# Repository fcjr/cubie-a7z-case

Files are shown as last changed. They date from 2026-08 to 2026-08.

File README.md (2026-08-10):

# Cubie A7Z case

A two-piece snap-fit case for the
[Radxa Cubie A7Z](https://radxa.com/products/cubie/a7z/). The board drops
into a tray, a lid clicks on top. No screws, no supports, no glue.

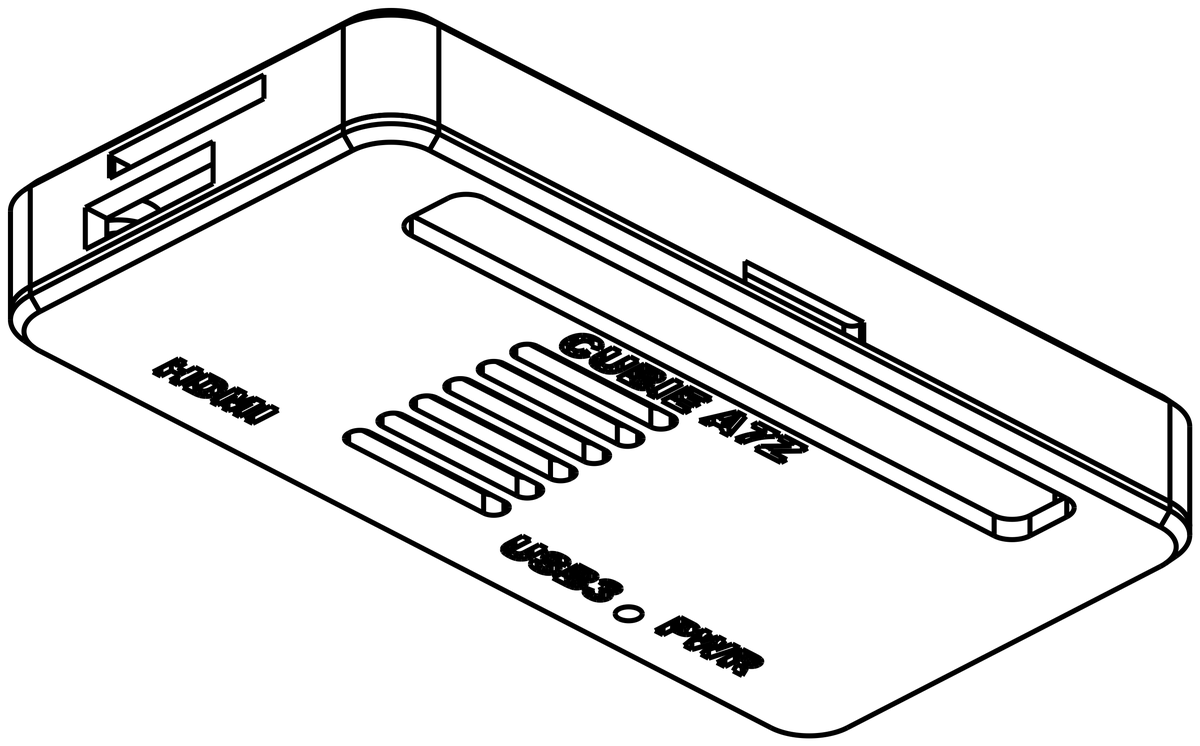
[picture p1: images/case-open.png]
The assembled case


## Print two parts

Everything ready to print is in [`output/`](output/). Take one tray and one
lid — any pairing works.

### Tray

|  |  |
|---|---|
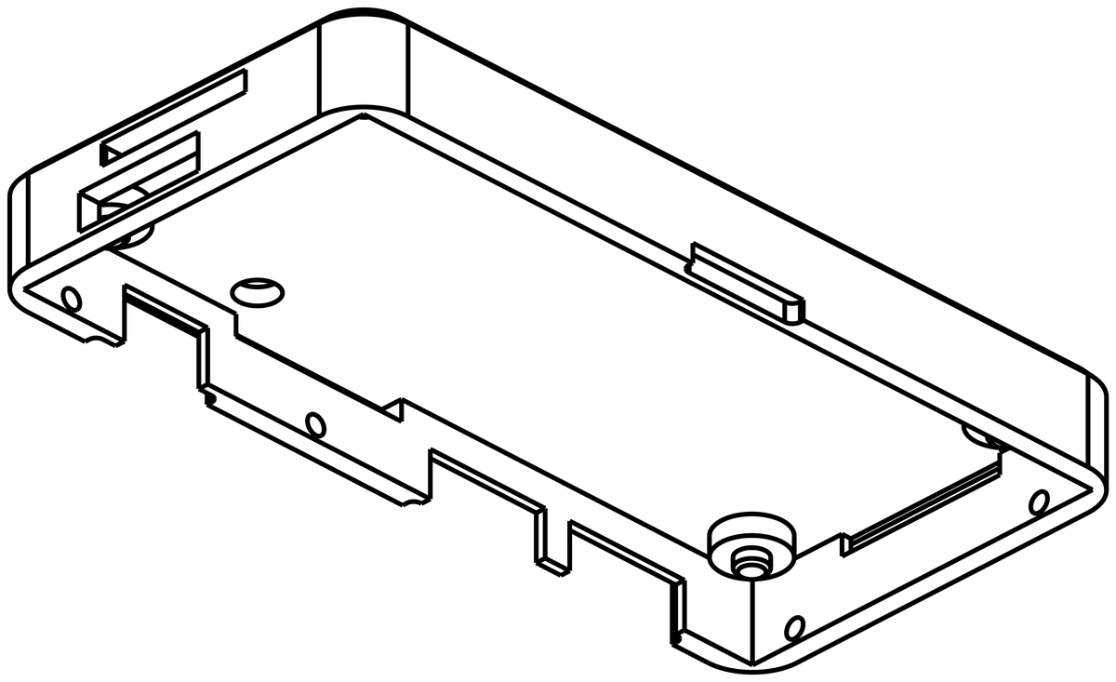
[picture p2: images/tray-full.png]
Tray with cable exits
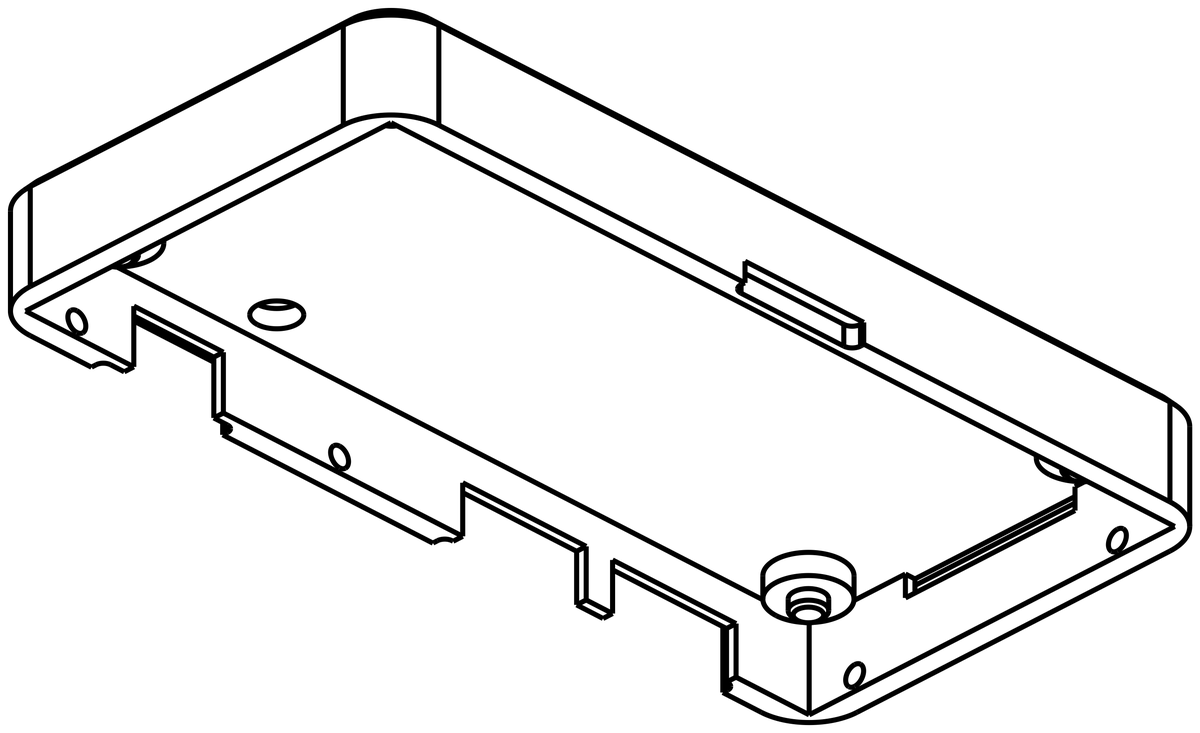
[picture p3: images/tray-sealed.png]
Sealed tray
|  |  |
| **`bottom.stl`** — openings for the PCIe ribbon, a CSI camera, the WiFi antenna and a fan. | **`bottom-sealed.stl`** — none of those openings, for a cleaner box. |

Every tray keeps the ports, the microSD slot and the boot button reachable.

### Lid

|  |  |  |
|---|---|---|
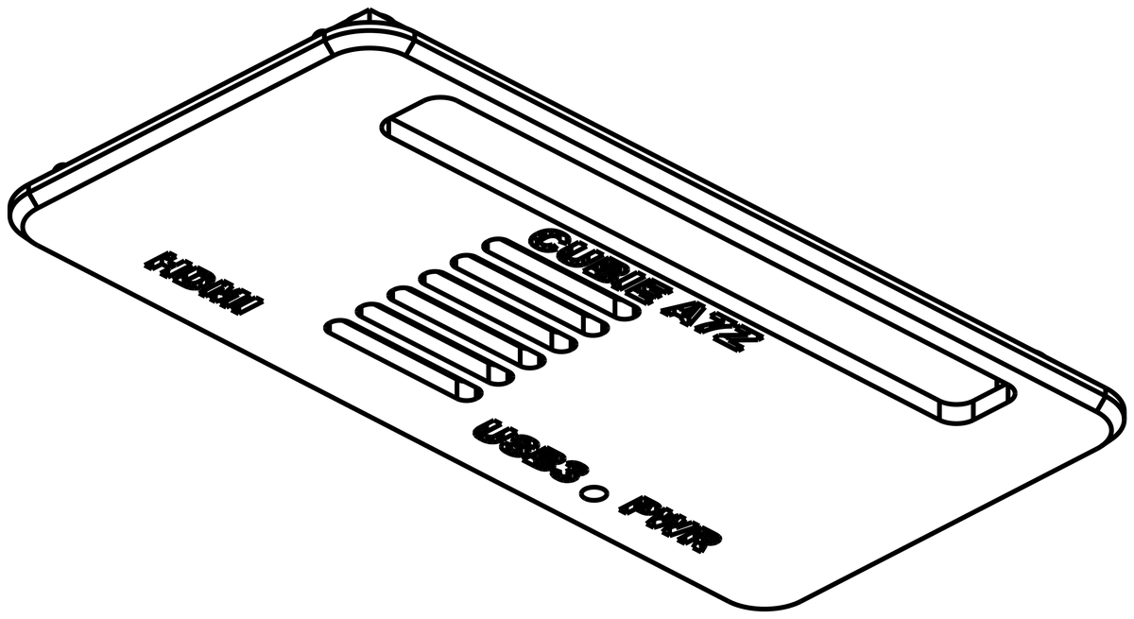
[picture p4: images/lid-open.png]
Lid with GPIO slot
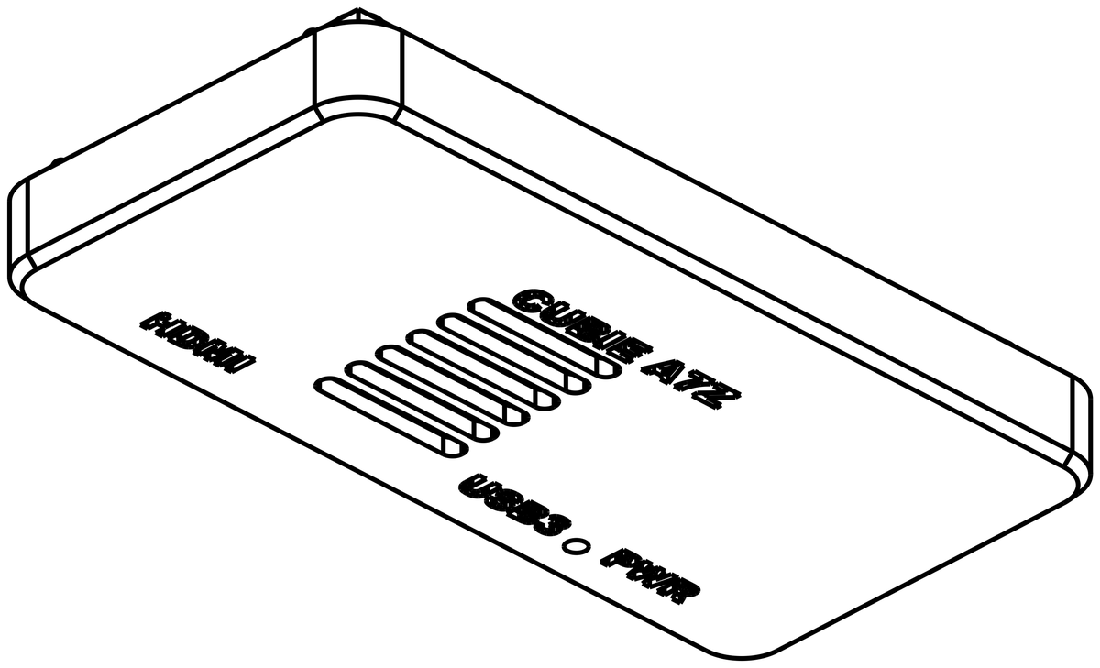
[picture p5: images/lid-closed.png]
Closed lid
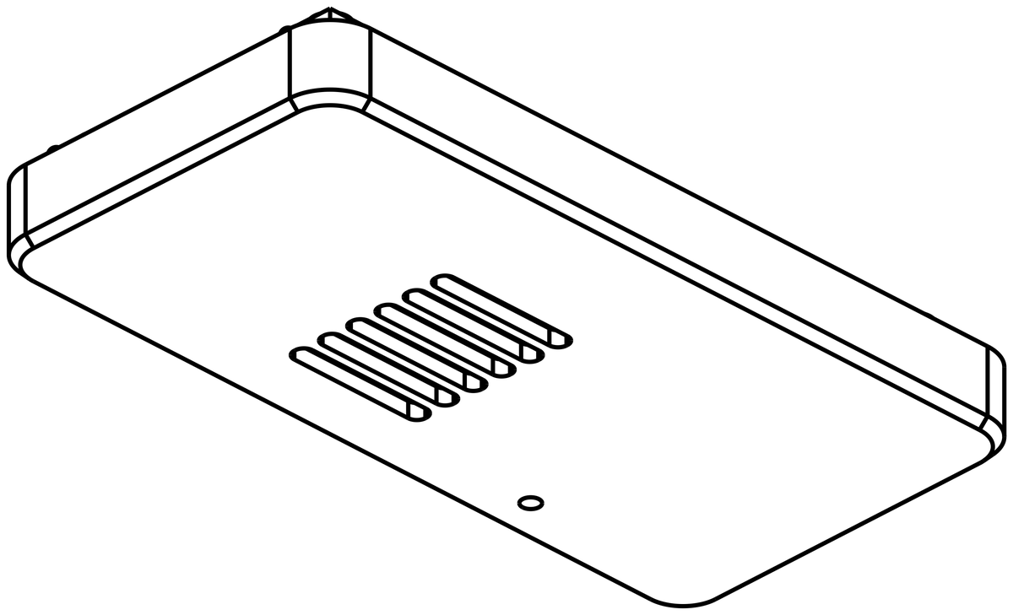
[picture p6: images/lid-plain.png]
Closed lid, no text
|  |  |  |
| **`lid.stl`** — the 40-pin header pokes through, ready for jumper wires and female headers. | **`lid-closed.stl`** — covers the header, 5 mm taller. | **`lid-closed-plain.stl`** — the same lid with no engraving. |

The case is 34 × 69 mm, and **9.1 mm** tall with the open lid or 14.2 mm
with a closed one.

### Or go slim

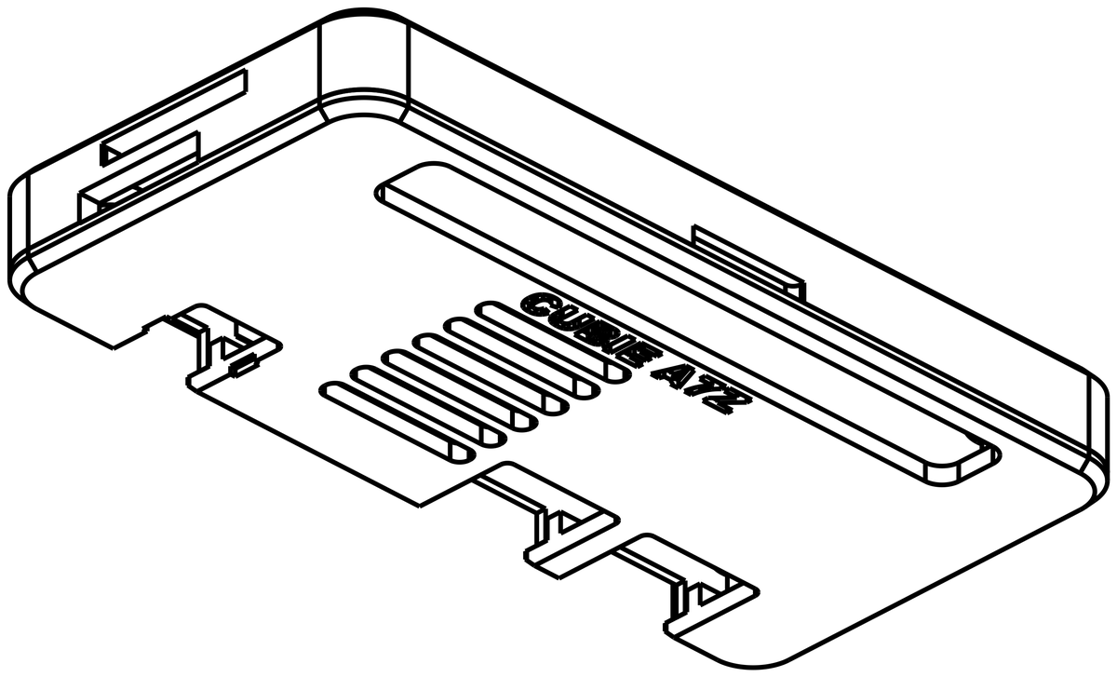
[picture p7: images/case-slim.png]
The slim case


If you're not running a fan, there's a shorter pair that drops the case to
**7.8 mm** — `bottom-slim.stl` (or `bottom-slim-sealed.stl`) with
`lid-slim.stl`.

The slim port side

The cavity is cut down to just clear the tallest chip on the board, which
leaves no room to route a fan lead. It also puts the lid below the USB-C
shells, so the port openings carry on up through the lid and open at the
top edge rather than being closed off by it — you can see the difference
against the standard case above. Slim parts only fit each other, not the
standard ones.

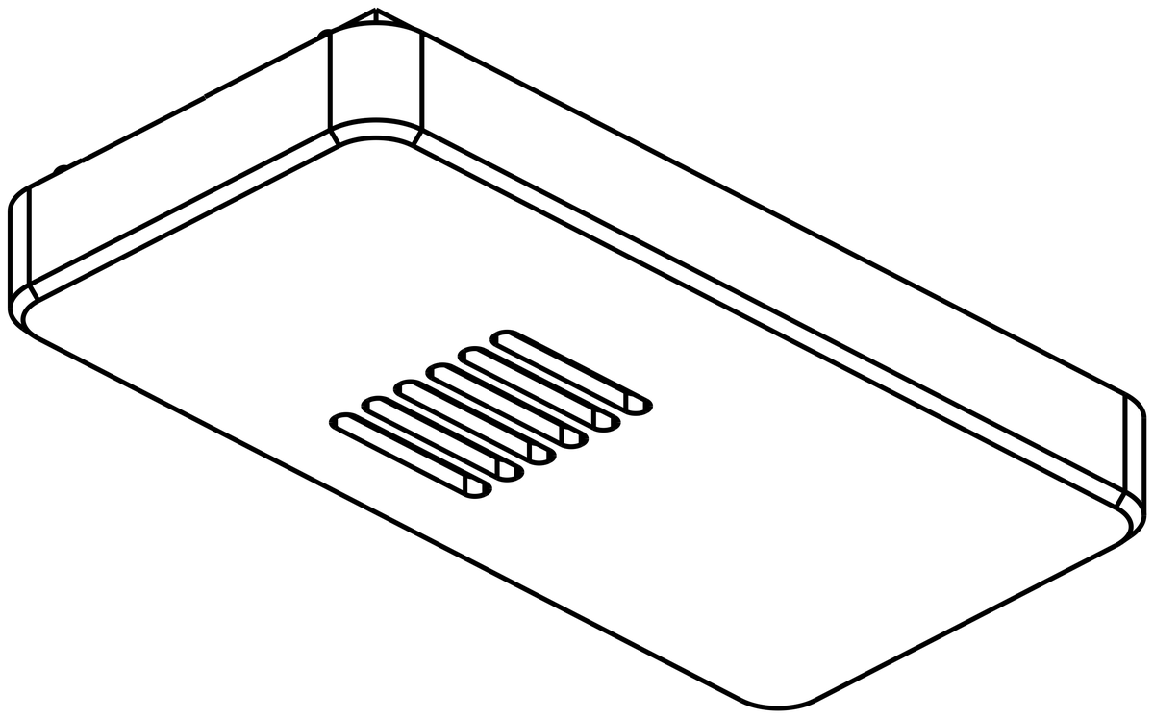
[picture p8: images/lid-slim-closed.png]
Slim closed lid


`lid-slim-closed-plain.stl` is the other lid for a slim tray: no GPIO
opening, no engraving, nothing on top but the vents. Covering the 40-pin
header is what sets its height, so the case comes out at 14.2 mm — the same
as the standard closed lid, and no shorter for being slim underneath.

No slim lid has the status-LED pinhole. It would have to be drilled through
the 0.95 mm fin left standing between the two USB-C openings, which on a
slim lid run right through the slab.

## Settings

Any material works; pick PETG or ABS if the board will run warm.

- **0.2 mm layers, no supports, no brim.**
- Print the tray cavity-up and the lids exactly as they're exported — they
  are already flipped flat-side-down.

## Put it together

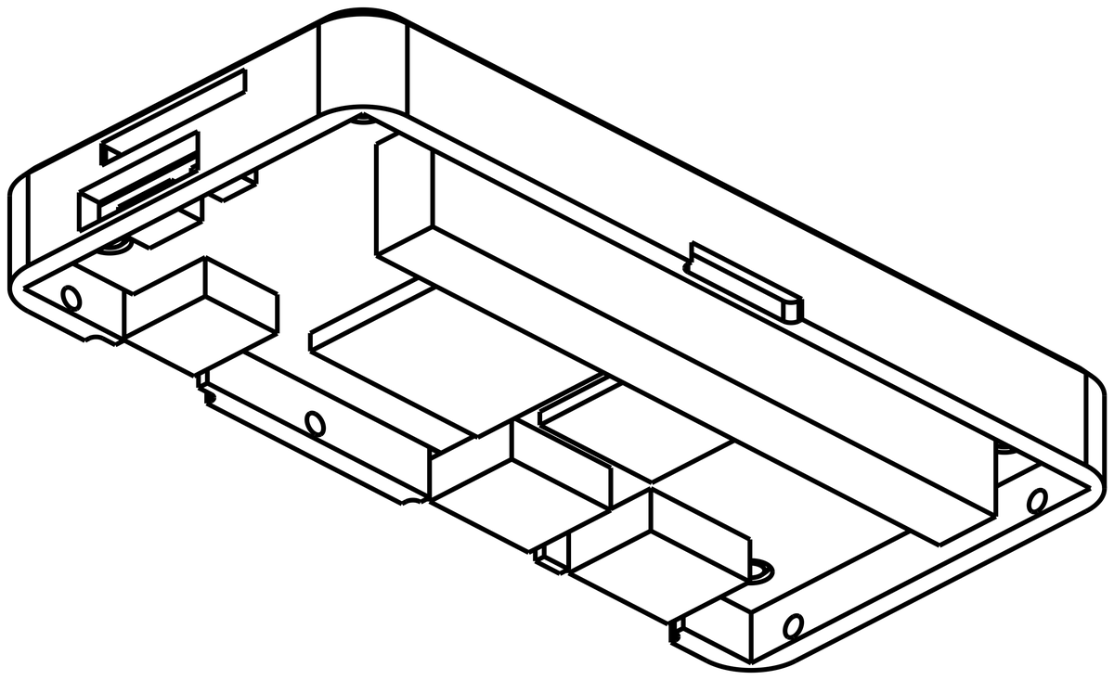
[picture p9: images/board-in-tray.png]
The board sitting in the tray


1. **Drop the board in**, ports facing the notched wall. Four pins catch
   its mounting holes, so it only fits one way round.
2. **Press the lid on.** Six ribs click into the tray and hold the board
   down against its standoffs.

To open it again, push up through the notch in the middle of the long
plain wall.

## Using it

The port side

Micro HDMI, USB-C 3.1 with DisplayPort, and USB-C power, left to right,
each labelled on the lid. The openings are recessed so a chunky cable
overmold still seats fully. The thin slot in the middle is where a PCIe
ribbon leaves the case. The pinhole between the two USB-C ports is the
status LED (standard lids only).

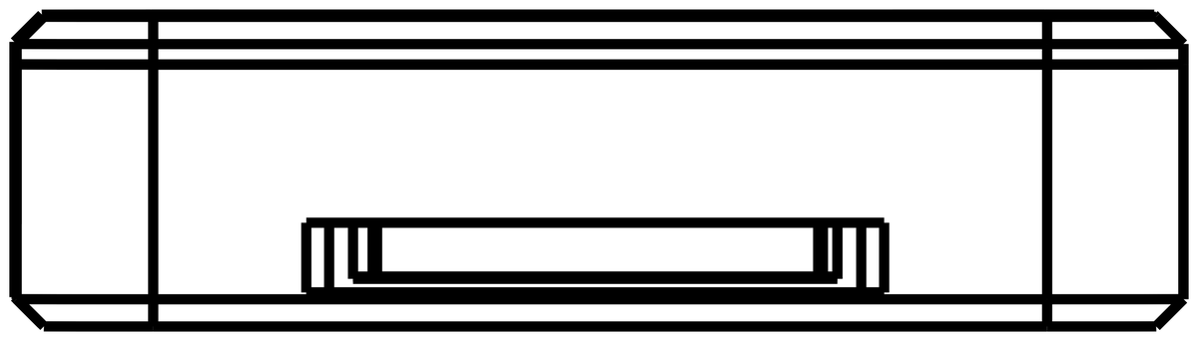
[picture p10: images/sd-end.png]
The microSD end


**microSD** goes in the end of the case nearest the power port, low in the
wall. A seated card ends up level with the outside face, so the wall around
the slot is scalloped back — that leaves an edge to pinch when you want the
card out again.

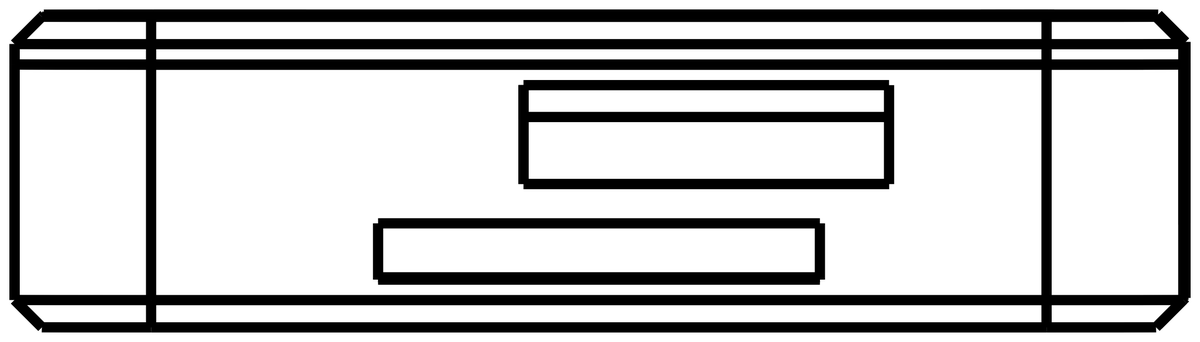
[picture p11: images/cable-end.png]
The cable end


The **other end** is where cables leave the full tray: the antenna pigtail
and fan lead through the upper slot, a MIPI CSI camera ribbon through the
lower one. The sealed tray has neither.

**USB BOOT**: hold a paperclip in the marked hole underneath — it's at the
HDMI end, behind the HDMI port — while you plug power in, and the board
comes up in flashing mode.

**Cooling**: the vents sit directly over the processor, and the full tray
passes a fan cable out the end.

## Two-colour text (optional)

If you have a multi-material printer, each engraved lid ships with a
matching inlay — `lid-inlay.stl` and `lid-closed-inlay.stl`. Load the lid,
add the inlay to it as a second *part* of the same object, colour it, and
print. The letters come out flush with the surface.

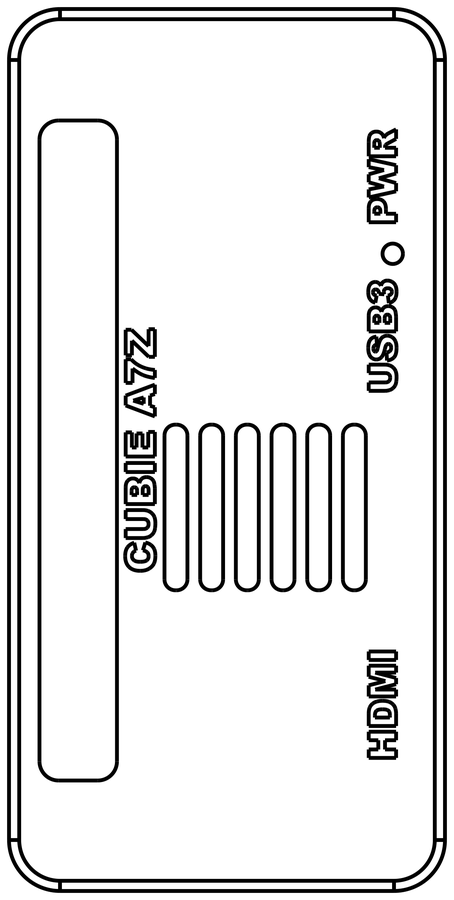
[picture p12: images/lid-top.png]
The engraved lid


## Building it yourself

The case is generated from a parametric
[CadQuery](https://github.com/cadquery/cadquery) model, dimensioned from
Radxa's published mechanical drawings and board STEP:

```sh
uv run case.py          # rebuild output/
uv run render_images.py # rebuild the images above
```

`case.py` rebuilds the board from the vendor STEP and checks every part
against it — fit, drop-in clearance, snap engagement, printability — and
refuses to export if anything is off. How it's dimensioned and why the
geometry is shaped this way is in [docs/DESIGN.md](docs/DESIGN.md).

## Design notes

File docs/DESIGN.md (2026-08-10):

# Design notes

How the case is dimensioned, why the geometry is the way it is, and what to
know before modifying `case.py`. For printing and everyday use, see the
[README](../README.md).

## Source data

Everything is dimensioned from Radxa's official mechanical releases, kept
in this directory:

- [product brief](https://dl.radxa.com/cubie/a7z/docs/radxa_cubie_a7z_product_brief.pdf)
  (rev 1.1) — interface list, 65 × 30 mm outline, Ø2.8 holes on a
  57.8 × 22.9 grid
- [2D DXF + dimension drawing](https://dl.radxa.com/cubie/a7z/docs/hw/Radxa_Cubie_A7Z_2D_DXF_V1.10.zip)
  (V1.10) in `2d/`
- [3D STEP of the board](https://dl.radxa.com/cubie/a7z/docs/hw/Radxa_Cubie_A7Z_3D_STP_V1.10.zip)
  (V1.10) in `3d/`
- [components placement map](https://dl.radxa.com/cubie/a7z/docs/hw/radxa_cubie_a7z_components_placement_map_v1.11.pdf)
  and [schematic](https://dl.radxa.com/cubie/a7z/docs/hw/radxa_cubie_a7z_schematic_v1.11.pdf)
  (v1.11)

The connector positions in `case.py` were probed solid-by-solid from the 3D
STEP (573 solids; each bounding box measured in board coordinates), not
transcribed from marketing drawings. Board coordinates: x across the width
(0 at the GPIO edge), y along the length (0 at the fan/antenna end), z = 0
at the PCB bottom face.

Two caveats found the hard way, both from the STEP modelling connectors as
unnamed truncated blocks rather than full bodies:

- **The STEP has no microSD holder in it at all**, and the block that looks
  most like one isn't. Two revisions were lost to this. The block at the
  y = 0 short edge, on the bottom, measures 10.80 × 3.25 × 1.00 — and
  10.80 mm reads convincingly like an 11.0 mm card, which is how it became
  the card slot. It is the MIPI CSI FPC connector. So is the 13.70 × 4.26
  block at the ports edge (PCIe). Neither is a card holder; both are FPC
  connectors whose ribbons leave under the board.

  The real microSD is at the **other** short edge, y = 65, on the bottom —
  the end with the power USB-C. Two sources outside the STEP agree, and
  they are what the model is dimensioned from now:

  - Radxa's interface photo (`docs.radxa.com/img/cubie/a7z/a7z-interface.webp`),
    scaled against the known 30.01 × 65.02 outline, puts the holder shell at
    x 9.7–20.6, y 52.1–57.4. The same photo, cross-checked on the three port
    shells down the right-hand edge (they land on HDMI 9.27–15.77,
    USB3 37.01–45.95, PWR 49.56–58.50 to within a few tenths), also shows
    the CSI FPC connector sitting at the y = 0 edge on the bottom face.
  - The bottom DXF carries the holder's contact row at x 11.14–18.84,
    y 57.85–58.93 — nine pads in microSD's 1.10 / 0.70 mm pitch pattern.

- Modelled depths are meaningless, so only footprint and hang below the
  board are used. The microSD holder's hang is not in the STEP either;
  1.4 mm is taken as a generic push-pull holder, which is what sets
  `BOTTOM_DROP` and has to fit inside the 1.6 mm standoff gap.

## Geometry decisions

- **Port notches, open to the top.** The HDMI and USB-C shells overhang the
  board edge by 1.0 mm, so the board can only drop vertically into the tray
  if the wall is open above each shell. The tray gets notches; the lid
  keeps its rim and closes them. The lid is only relieved where it must be:
  the friction lip is cleared over each port span (shells reach x = 31.0,
  z = 4.4 — the lip's territory).
- **Port opening height** is set by the cavity, not by choice: a notch runs
  from just under its shell to the top of the wall, so every millimetre of
  headroom above the tallest part shows up as a taller-looking port. The
  cavity is therefore pinned to the USB-C shells at 4.40 plus 0.3, and the
  plug-overmold recesses stop at the seam instead of running up into the
  lid rim — that band above the seam was what made the ports read as a
  slot from outside.
- **Two cavity heights**, both driven from `use_headroom()`:
  *standard* clears the USB-C shells (case 9.1 mm), so the lid closes over
  the port notches; *slim* clears only the 3.10 mm fan header (case
  7.8 mm). Nothing in between is available, and the reason is the plug, not
  the shell: a plug has to reach a connector whose mouth spans z 1.24–4.40,
  so any lid sitting below 4.40 must be cut away over the ports rather than
  roofing them. On the slim lid the notches therefore run through the slab
  and clear the shells' full 7.35 mm depth inboard of the wall, which is
  why its top edge is bitten into at each port. The remaining stack —
  1.4 floor, 1.6 standoff, 1.2 board, 1.4 lid — is already at the thin end
  of what prints well.
- **Standoffs and hold-downs.** The board rests on four Ø5.4 bosses with
  Ø2.4 pins through its mounting holes; pins stop 0.1 mm below the board
  top. The lid presses down with four Ø3.2 posts landing on the bare
  mounting-hole pads — the only reliably clear spots on a board this
  dense. Bottom-side parts hang at most 1.4 mm — the microSD holder — into
  the 1.6 mm standoff gap.
- **GPIO.** The header comes populated and is 8.3 mm tall — 4.3 mm more
  than the cavity. The open lid slots it (sized for 5.08 × 50.8 mm female
  header housings; IDC ribbon sockets are wider and won't fit). The closed
  lid raises its whole top by 4.6 mm instead: a flat raised top still
  prints face-down with no supports, where a local blister over the header
  would hover above the bed once flipped.
- **microSD.** A 14 mm-wide slot through the y = 65 short wall, under board
  level — the card rides in the holder's hang below the PCB — running the
  full standoff gap. Both trays have it; card access isn't optional.

  A 15.0 mm card bottoms out with its leading edge at the back of the shell
  (y ≈ 52.2), which puts its other end at y ≈ 67.2 — level with the outer
  wall face at 67.12. Flush is nothing to pull on, so the outer 1.0 mm of
  wall is scalloped away over a 20 mm span around the slot, and the card
  stands that much proud of the surface a fingertip reaches. The scallop
  stays below board level and clear of the two snaps on that wall.
- **Snap closure.** Friction lip (1.2 × 1.6 mm, 0.15 clearance per side)
  with six rib/groove pairs: two per short wall, two on the ports wall
  between the notches, each placed clear of that wall's openings. The GPIO
  side gets none — the header opening eats the lip along that edge on the
  open lid, and even the closed lid trims it there because the lip's inner
  face (x = 1.05) would overlap the header body (x from 0.79).

  The geometry is lifted from the restorekit dongle cases, which lock
  well in the hand: a 0.6 dome on the lip against a 0.75 socket in the
  wall. Offset by the 0.15 lip clearance, the two are internally tangent
  when seated — the dome drops fully home rather than riding the socket
  rim — while still having to squeeze 0.45 mm past the wall going in,
  which is the click you feel.

  A 45° diamond rib was tried in between, on the theory that a sphere's
  underside is an unprintable overhang and 0.45 mm was more flex than a
  closed 1.2 mm lip loop could give. Both worries were wrong in practice:
  the dome is 0.6 mm across and prints without support, and the loop
  closes fine. What the rib got wrong is retention — symmetric 45° ramps
  cam out as easily as they cam in, so it shut softly and pulled apart.
  Retention wants a face perpendicular to the pull; printability wants one
  at 45°; the dome splits the difference by being steep only near its
  equator.
- **Fillets and chamfers** follow the print orientation. Vertical-axis
  fillets (the 4 mm body corners, the vent ends, the GPIO slot, the port
  openings) are free — they never overhang. The two bed-facing edges get
  45° chamfers instead of fillets: a fillet there curves out to a 90°
  overhang on the first layers, a chamfer doesn't.
- **Pry notch.** A scallop in the GPIO-side wall top, open upward so it
  needs no support, positioned where the lid has no lip anyway.
- **Cable exits** (full tray only), all at the y = 0 end or the ports wall:
  an antenna/fan notch over the y = 0 wall, a CSI ribbon opening under the
  same wall (that connector is on the board's bottom face, so its ribbon
  leaves below the board rather than over it), and a PCIe FPC slot in the
  ports wall between the HDMI and USB-C notches, also below board level.
  The lids are cut by the same solids — on a lid they only trim the hidden
  lip, which is why either lid also fits the sealed tray.
- **Status LED window.** A Ø1.6 pinhole through the lid slab over the
  emitter, which sits in the 2.2 mm gap between the two USB-C ports. It has
  to thread a needle — at Ø2.0 it nicked both the lip's inner face and the
  power port's notch by about 0.05 — so a build-time check reports its three
  clearances and fails if any drops below 0.1 mm.

  Standard lids only. On a slim lid the port notches run through the slab,
  which turns the material the window would pass through into a 0.95 mm fin
  between two openings, so the slim lids don't get one.
- **Boot button.** A 3.00 × 2.50 × 1.00 tact switch on the board underside
  at (27.51, 17.94) — just behind the micro HDMI port, not under the power
  port, where an earlier revision put it after picking a similar-looking
  3.70 × 1.60 part at y ≈ 52. Two independent checks agree: the placement
  map's `SW1` designator lands at (26.95, 17.95) once the bottom view's
  mirrored x is undone, and the hardware confirms the HDMI end. The floor
  gets a Ø3.2 poke hole with a mirrored `BOOT` engraving that reads
  correctly from below, its ink stopping 0.7 mm clear of the hole. The
  engraving is placed off `SW1` rather than off a literal: when the switch
  moved to its real position the label didn't follow, and sat 36 mm away at
  the wrong end of the case for a revision.

## Self-checks

`case.py` refuses to export if anything is wrong, so a bad edit fails the
build instead of failing the print:

- **Fit**: a mock board rebuilt from the probed STEP solids must have zero
  intersection with every tray and lid, both seated and swept vertically
  (the drop-in path), and each lid must clear each tray.
- **Stroke width**: the fonts are measured, not trusted — a stem of the
  actual rendered face must come out ≥ 0.65 mm, so a missing Arial Black
  silently falling back to something lighter can't produce unprintable
  text.
- **Piece width**: the stem check misses sub-stem features (a lowercase
  i's dot is narrower than its stem — the reason the wordmark is
  uppercase), so the narrowest loose inlay piece is also gated at 0.6 mm.
- **Snap engagement**: the interference each rib asks the lip to flex over
  must land between 0.12 and 0.30 mm, and the part of the rib that reaches
  into the wall must sit entirely inside its groove — a rib that bottoms
  out jams instead of clicking.
- **Printability**: every part must be a **single connected solid**, and no
  face may point downward more steeply than 45° in print orientation. The
  connectivity half of this is not theoretical: it caught the closed lid
  shipping as five separate solids, its whole lip — and four of the six
  snaps — floating under the cap with nothing joining them to it, because
  hollowing the cap to the full cavity footprint had removed the material
  directly above the lip. Ceilings over an opening (the microSD slot, the
  cable notches, the engraved letters) are bridges anchored on both sides
  and print fine, so they are reported as an area rather than failed.

## Engraving

Arial Black, 0.6 mm deep with flat bottoms. The font is picked for stroke
width, not looks: a 0.4 mm nozzle wants ~0.8 mm strokes so each letter stem
gets two perimeters, and free-standing inlay letters get dropped by the
slicer if they come in under a nozzle width. Arial Black stems measure
0.222 × size against Arial Bold's 0.145 — 53% more stroke for 9% more
width (the scheme comes from the restorekit dongle cases).

The lid layout is set by the two big openings: the GPIO slot owns one side
and the vent field owns the middle, so the wordmark runs lengthwise in the
strip between them and the port labels run lengthwise above their ports.
All marks are built in absolute coordinates and cut in a single pass —
re-selecting `faces(">Z")` between engravings starts matching the coplanar
islands inside letter counters and sends later marks astray. Each mark is
snapped to its ink bounding box before placement because CadQuery centres
text on font metrics, not on the ink it draws.

## White text inlay

Each `*-inlay.stl` is exactly the volume of its lid's engraved pockets,
exported in the same orientation — union the two and you get a flat-topped
lid with no interference and no gap (verified: 0.000 mm³ intersection and
0.000 mm³ residual).

With a multi-material printer: load the lid, add the inlay to it as a
second *part* of the same object (not a separate object, so it isn't
re-centred), assign a colour, print top-face-down. Single extruder: print
the inlay on its own and glue the letters in — but note the fit is
zero-clearance by construction, so give the inlay a little slicer XY
compensation (or a light sand) or the letters won't drop in.

A plain filament swap does *not* work: the lid prints top-face-down with
the text recessed, so the letters are voids in the first layers — swapping
colours the top face and leaves the letters in the body colour, the inverse
of what you want.

## Working on the model

- `uv run case.py` — rebuilds `output/`. All dimensions live in the
  parameter block at the top of `case.py`, with the probed board facts
  separated from the case design choices.
- `uv run render_images.py` — regenerates the README images in `images/`
  (runs the full build first; rasterising uses macOS `qlmanage`).
- The checks print their interference volumes on every run; keep them at
  zero. If you move or resize a mark, the stroke/piece gates re-verify it
  automatically.

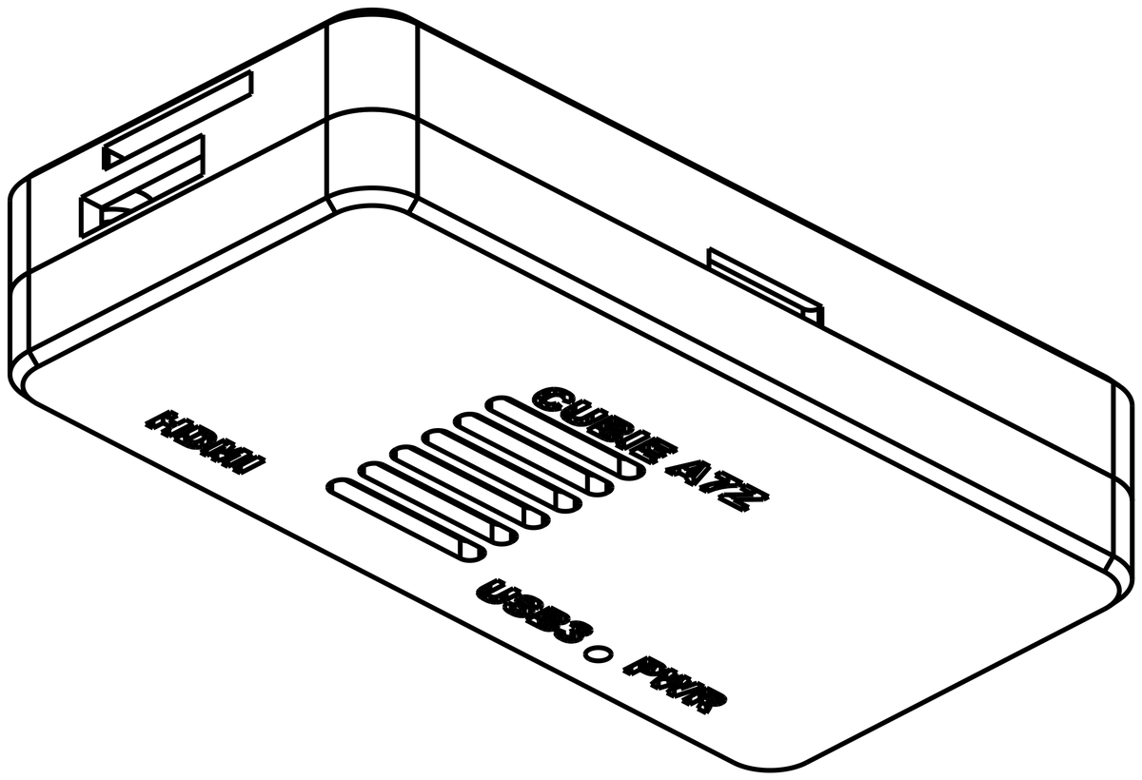
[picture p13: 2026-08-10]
images/case-closed.png

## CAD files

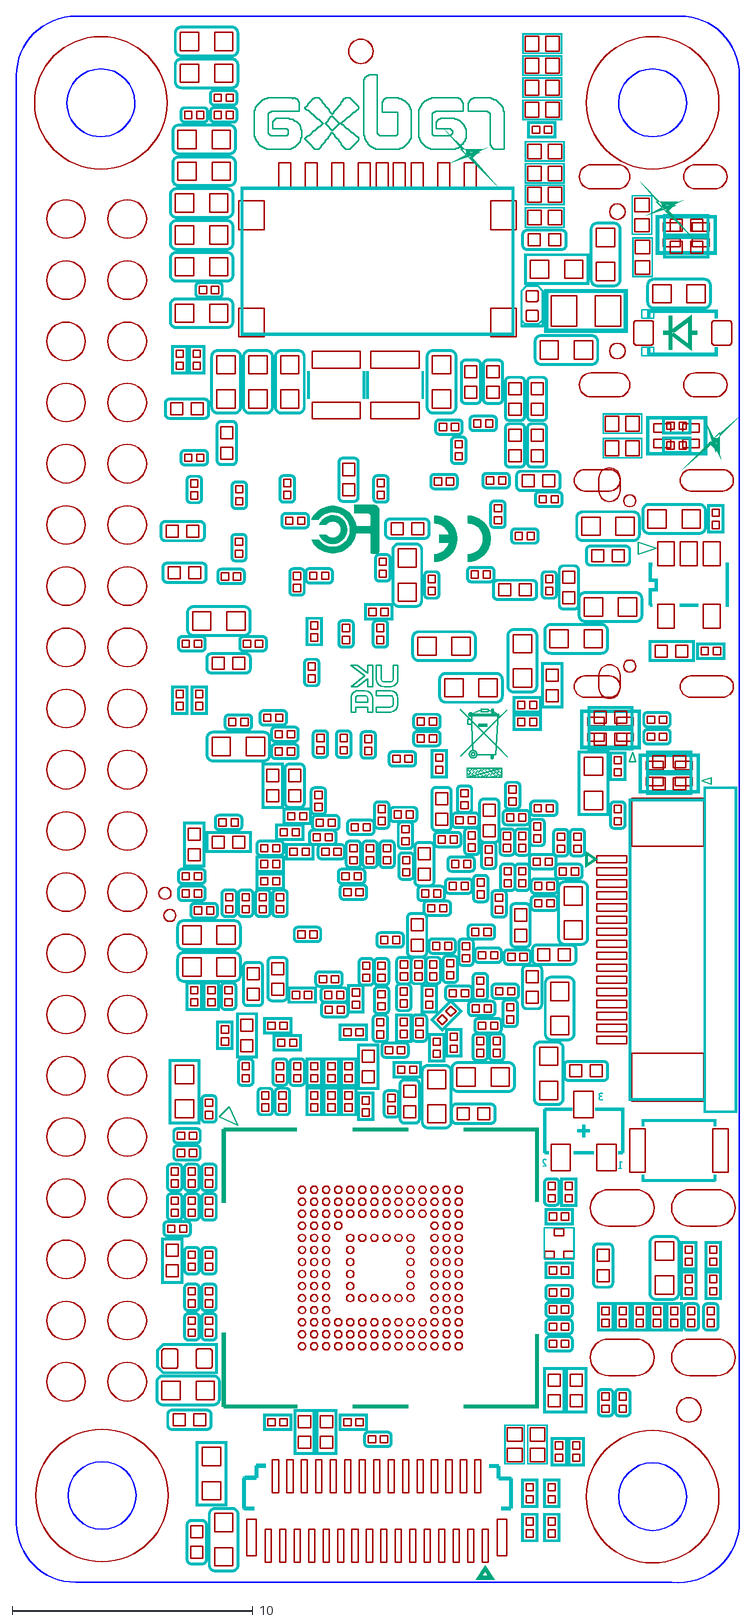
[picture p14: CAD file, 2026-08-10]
docs/2d/Radxa_Cubie_A7Z_2D_V1.10-BOTTOM.dxf
3
2
1

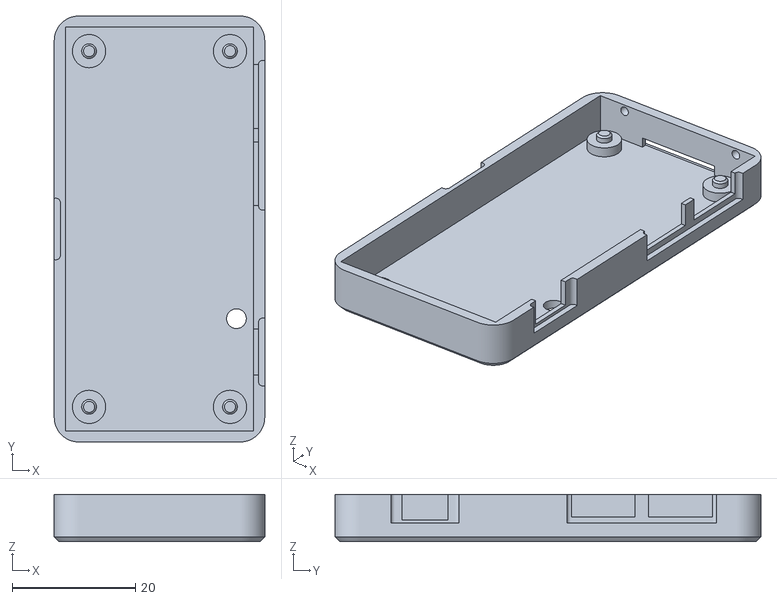
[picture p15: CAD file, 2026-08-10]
output/bottom-sealed.stl
34.2 x 69.2 x 7.70

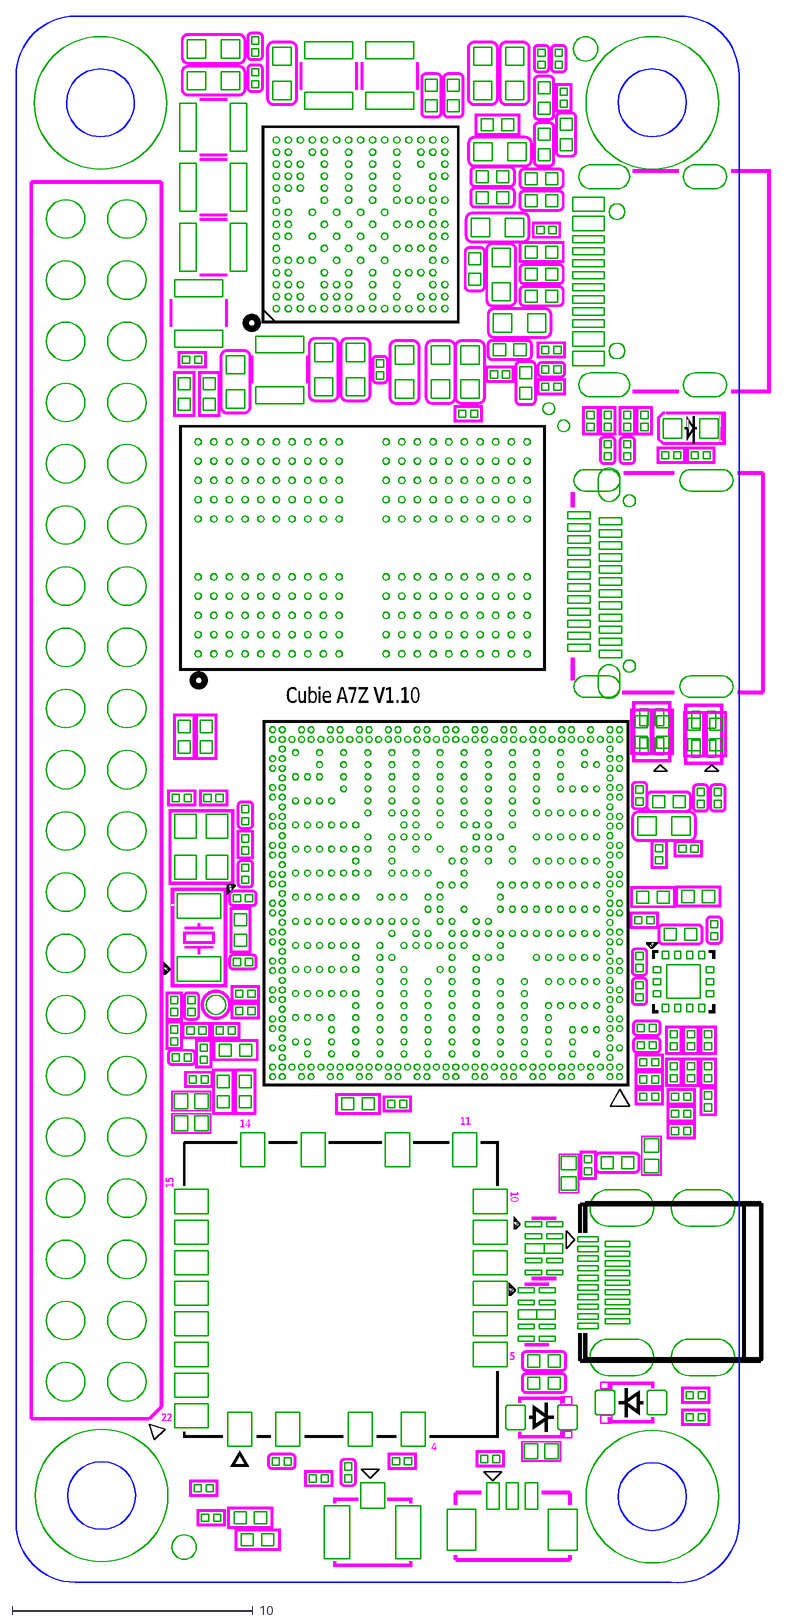
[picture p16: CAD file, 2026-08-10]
docs/2d/Radxa_Cubie_A7Z_2D_V1.10-TOP.dxf
4
5
10
11
14
15
22
Cubie A7Z V1.10

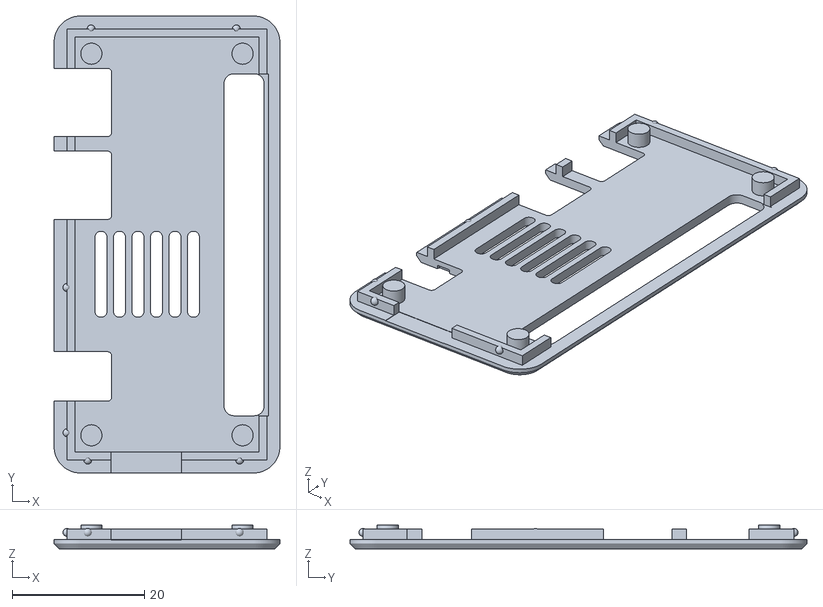
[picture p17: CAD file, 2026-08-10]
output/lid-slim.stl
34.2 x 69.2 x 3.60

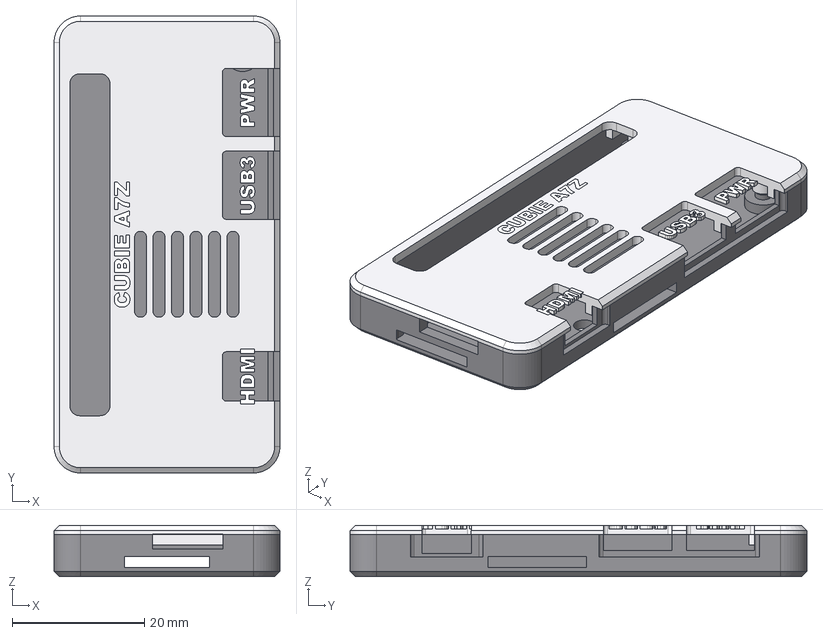
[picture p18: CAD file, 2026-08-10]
output/cubie-a7z-case-slim.step
34.2 x 69.2 x 7.80 mm
bottom
lid
inlay

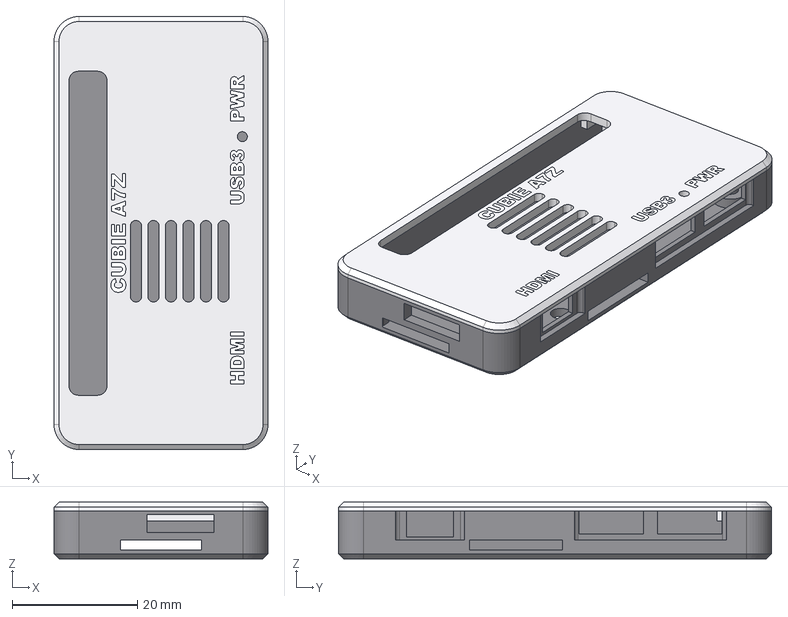
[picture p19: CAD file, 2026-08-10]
output/cubie-a7z-case.step
34.2 x 69.2 x 9.10 mm
bottom
lid
inlay

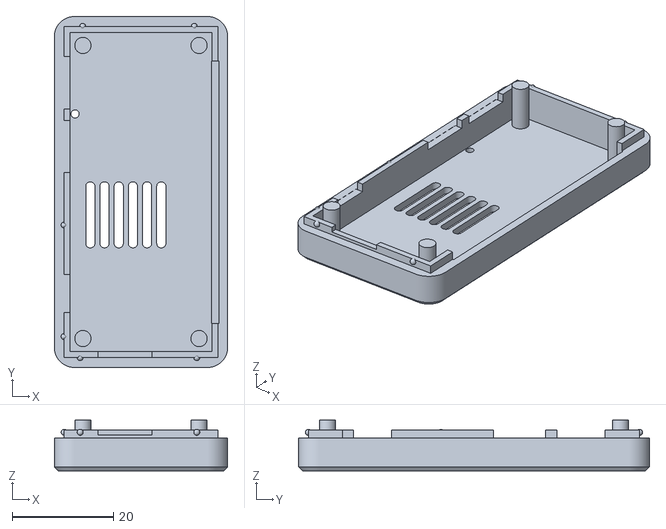
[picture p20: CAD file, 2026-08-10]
output/lid-closed.stl
34.2 x 69.2 x 10.00

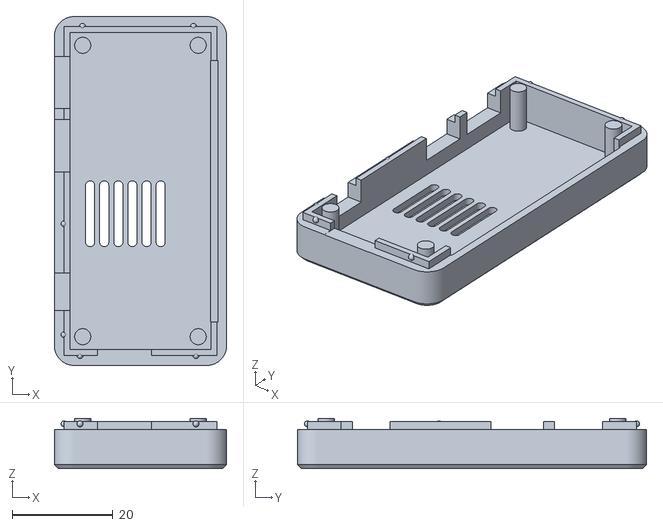
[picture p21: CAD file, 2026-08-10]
output/lid-slim-closed-plain.stl
34.2 x 69.2 x 10.00

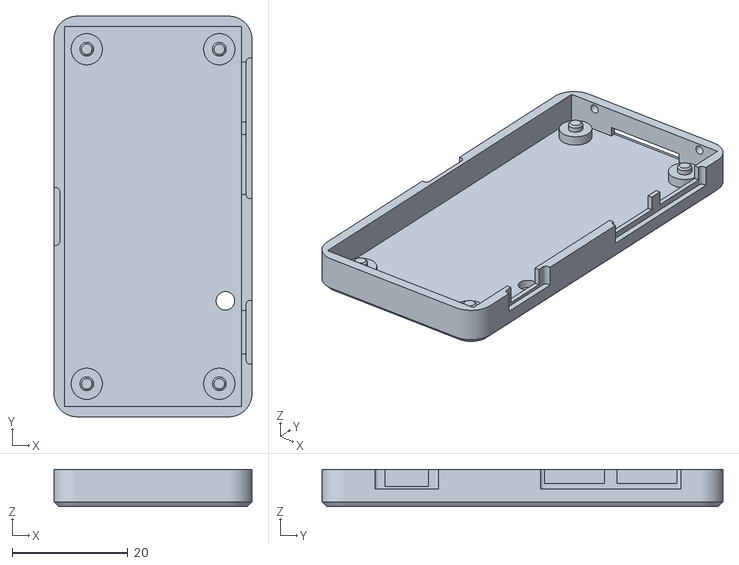
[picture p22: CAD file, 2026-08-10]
output/bottom-slim-sealed.stl
34.2 x 69.2 x 6.40

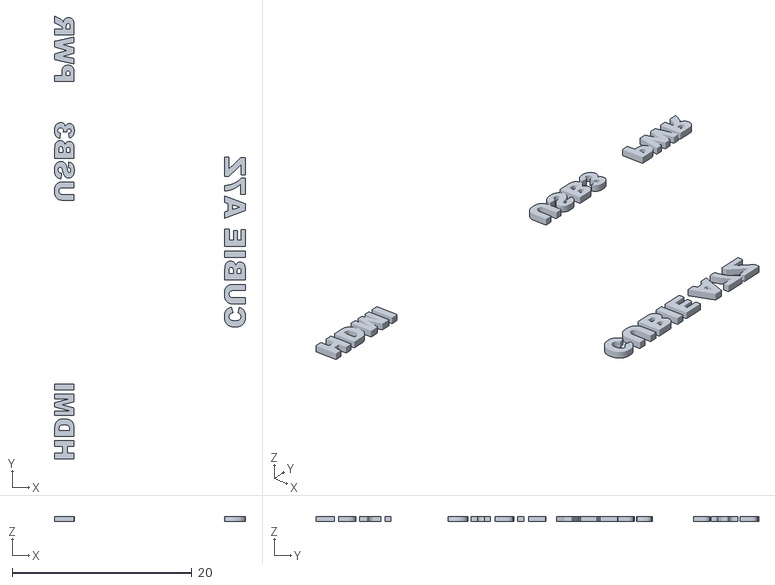
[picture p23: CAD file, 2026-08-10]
output/lid-slim-inlay.stl
21.3 x 49.3 x 0.6

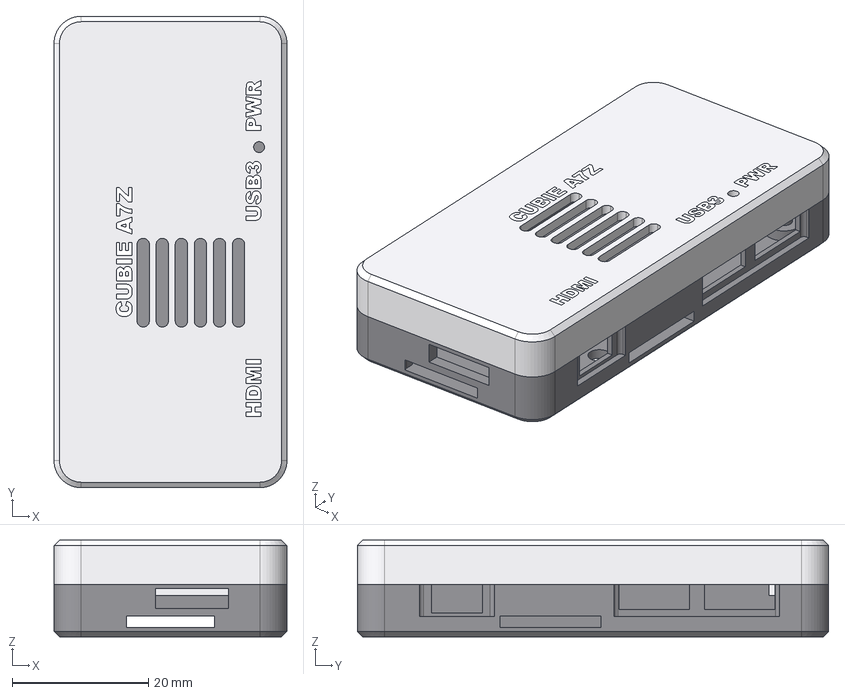
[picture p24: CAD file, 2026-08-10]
output/cubie-a7z-case-closed.step
34.2 x 69.2 x 14.2 mm
bottom
lid
inlay

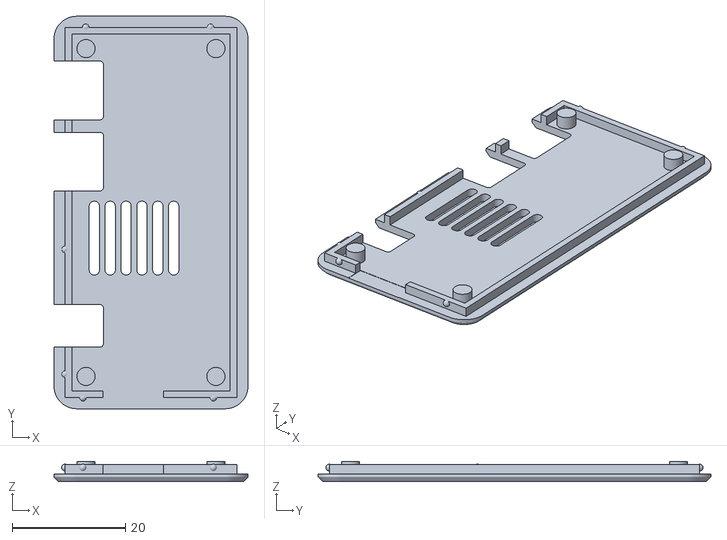
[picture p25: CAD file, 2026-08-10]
output/lid-slim-plain.stl
34.2 x 69.2 x 3.60

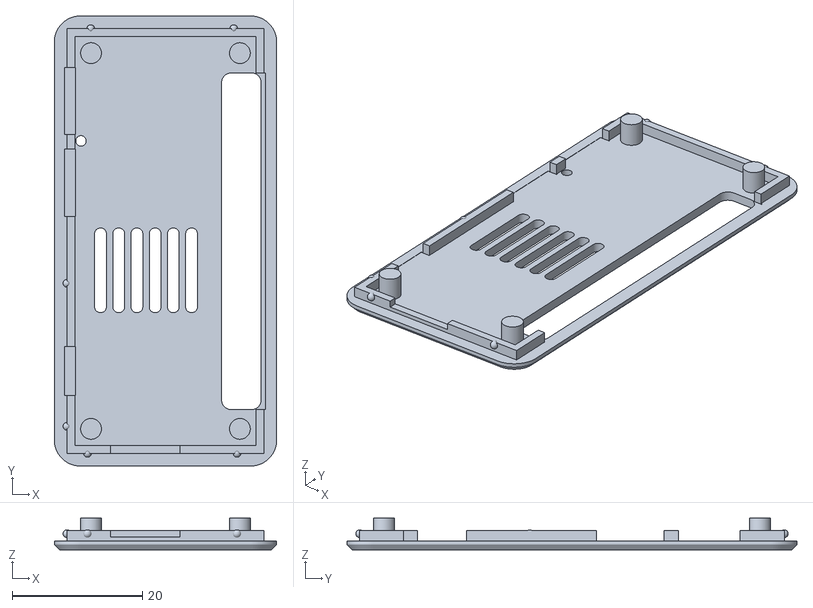
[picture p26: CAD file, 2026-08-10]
output/lid.stl
34.2 x 69.2 x 4.90

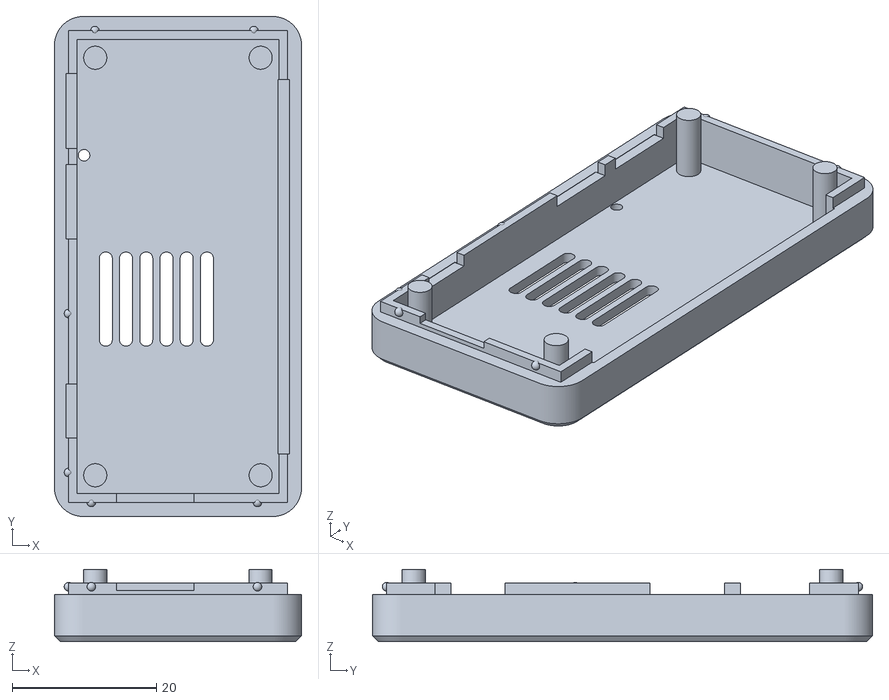
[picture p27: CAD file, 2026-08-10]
output/lid-closed-plain.stl
34.2 x 69.2 x 10.00

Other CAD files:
output/bottom.stl
output/lid-closed-inlay.stl
output/bottom-slim.stl
output/lid-inlay.stl

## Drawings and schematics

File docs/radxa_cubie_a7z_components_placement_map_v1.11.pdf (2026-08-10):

# ART FILM - ass-top

# HOLE4

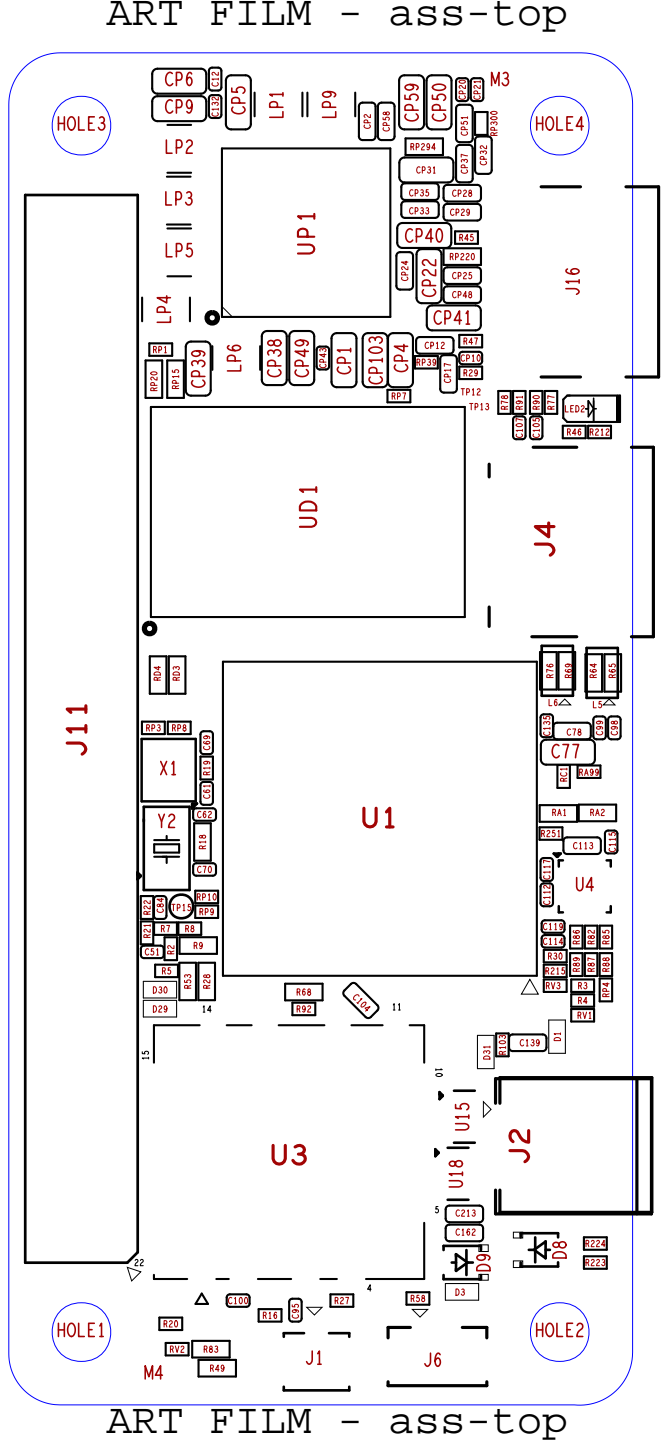
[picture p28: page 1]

ART FILM - ass-top

# ART FILM - ass-bot

D2

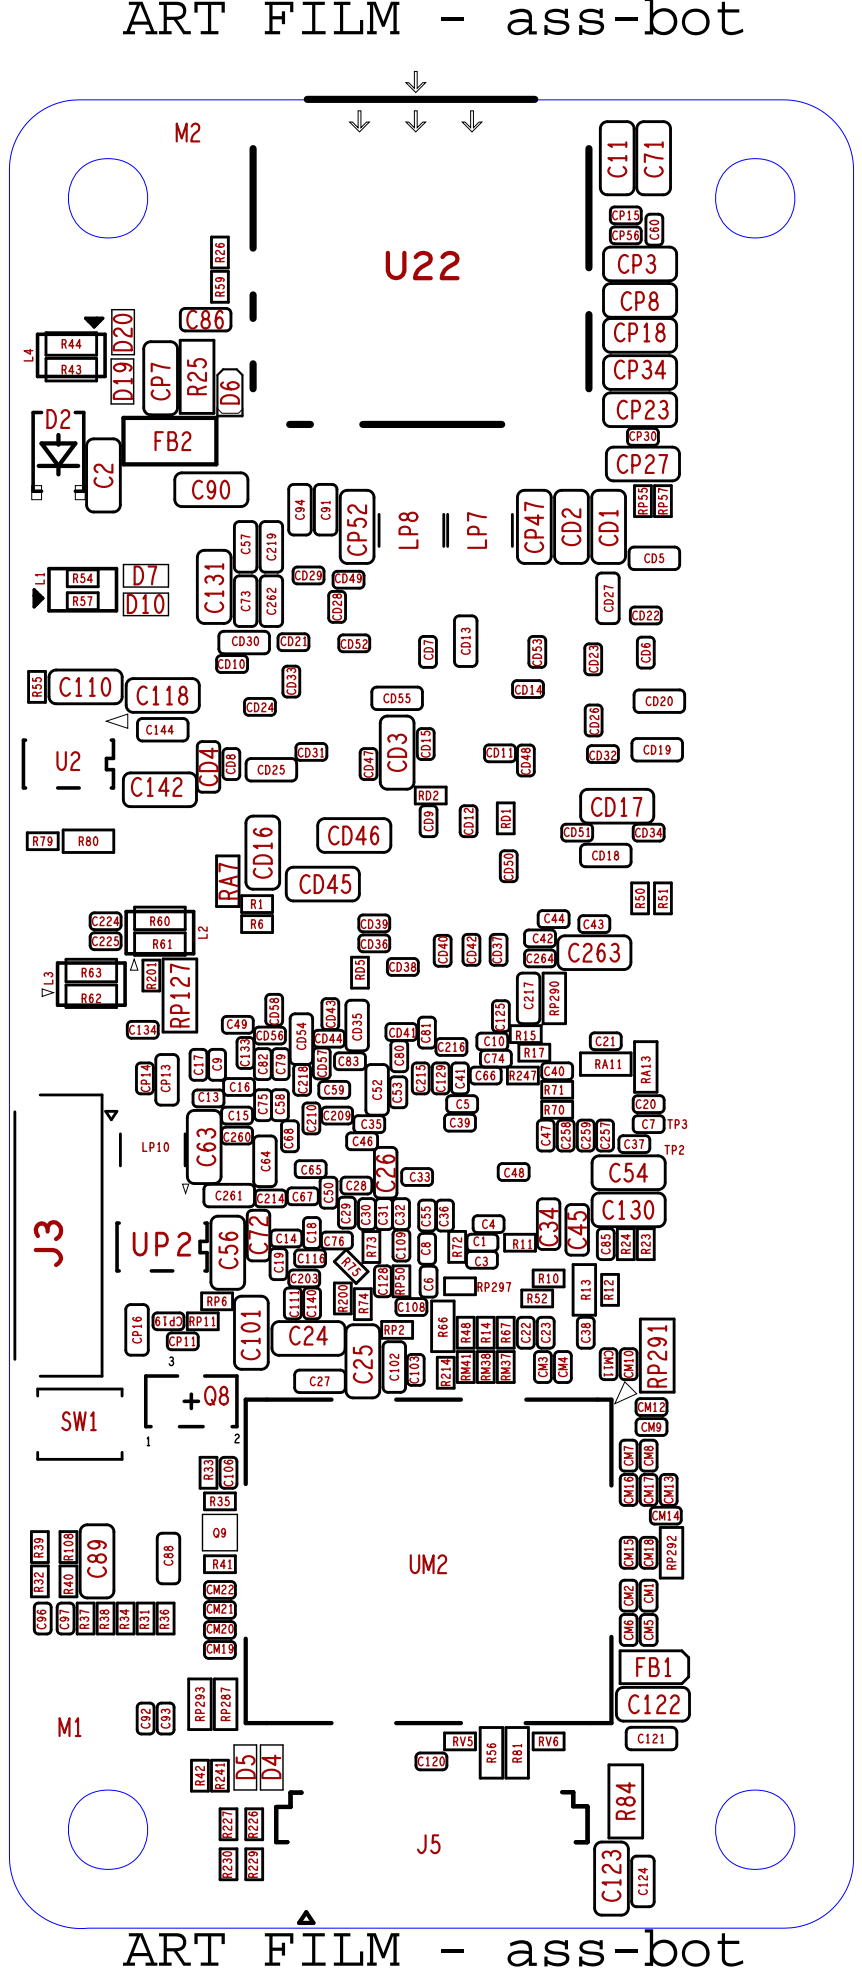
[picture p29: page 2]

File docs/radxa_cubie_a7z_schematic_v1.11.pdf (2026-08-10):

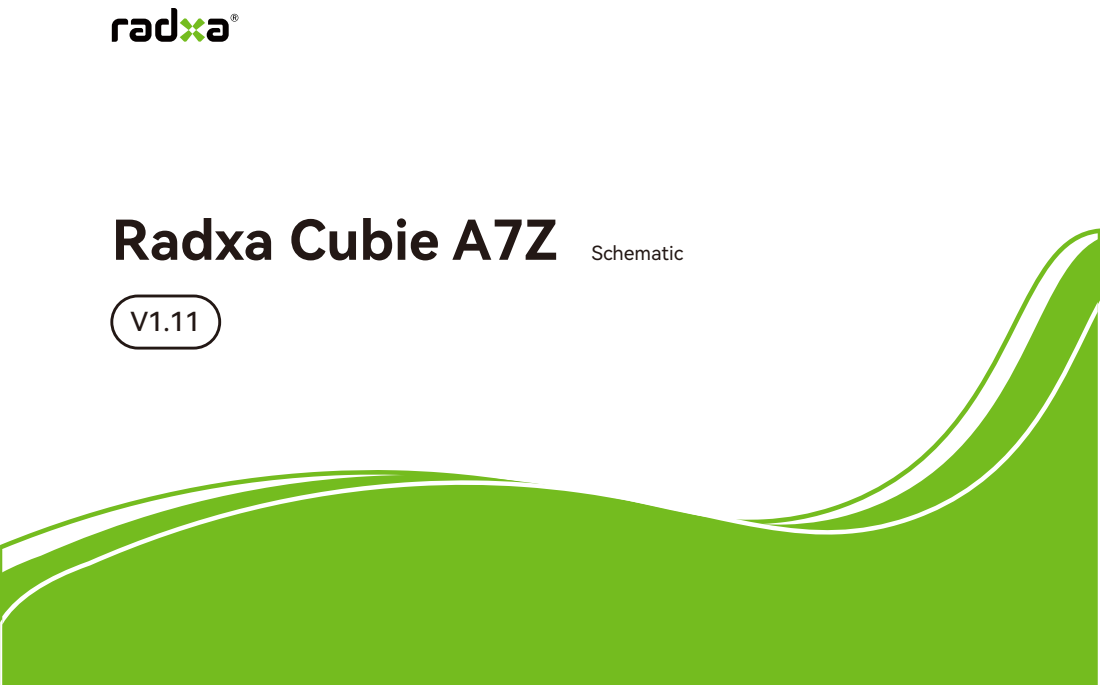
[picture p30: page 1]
Radxa Cubie A7Z; Schematic

D | D

# 02.Index

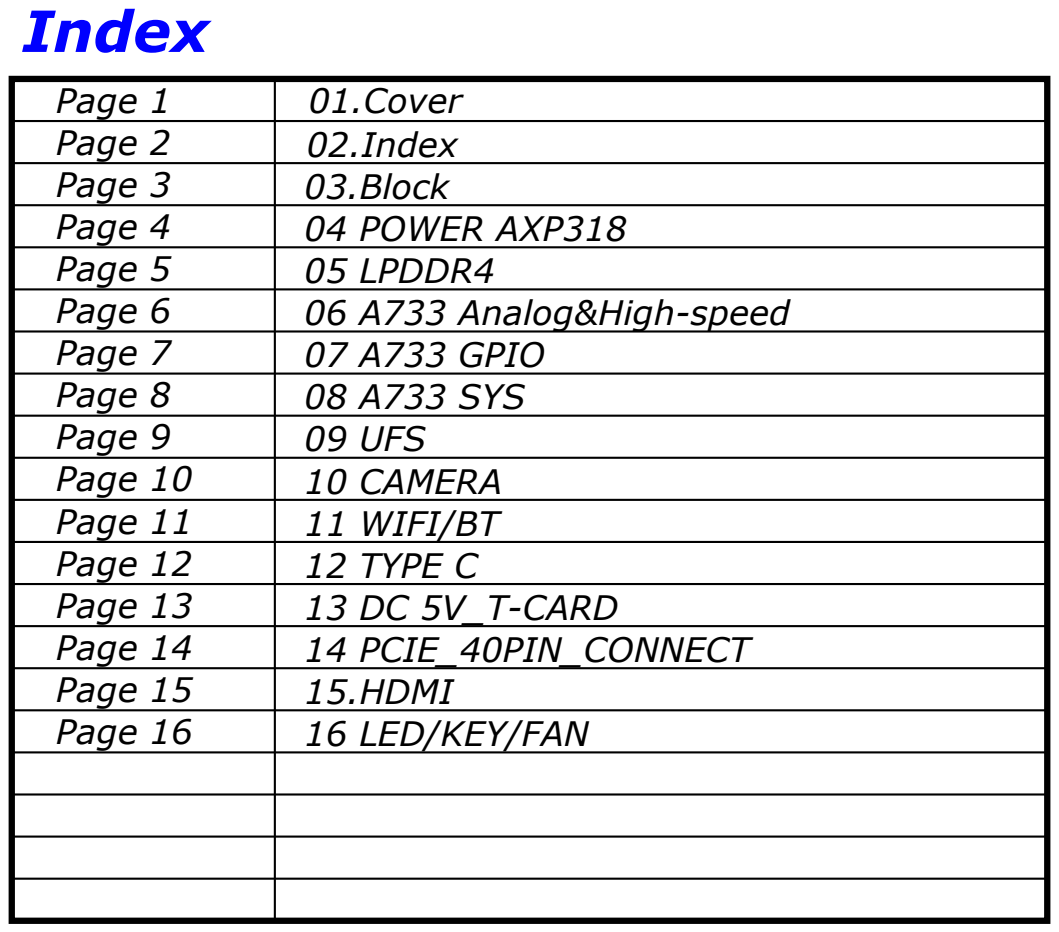
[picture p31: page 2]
Page 10 Page 11; Page 16; Page 7; Page 14; Page 5; Page 8; Page 2 Page 3 Page 4; Page 6; Page 9; 01.Cover; Page 15; Page 13; Page 12; Page 1; 03.Block; Index; 04 POWER AXP318 05 LPDDR4 06 A733 Analog&High-speed 07 A733 GPIO 08 A733 SYS 09 UFS 10 CAMERA 11 WIFI/BT 12 TYPE C 13 DC 5V_T-CARD 14 PCIE_40PIN_CONNECT 15.HDMI 16 LED/KEY/FAN; Size; REV; Date:; Sheet; Title:; Page Name:; 02 INDEX; Monday, December 08, 2025

DDR | TF

# UFS

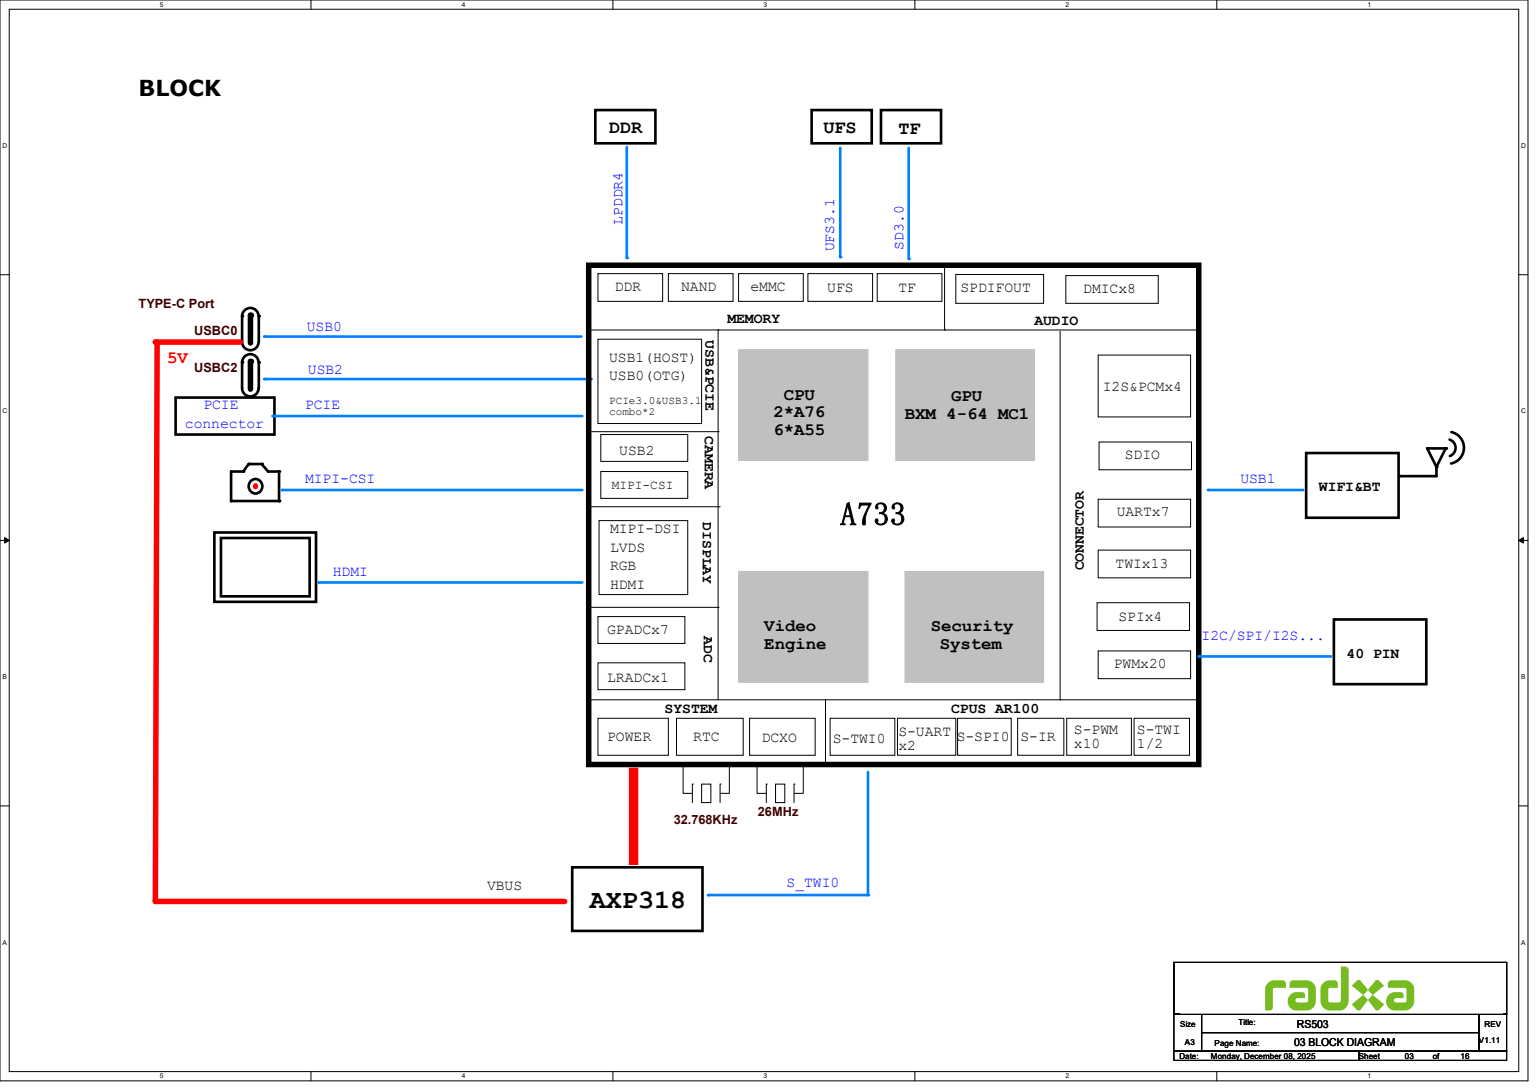
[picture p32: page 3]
CPU 2*A76 6*A55; GPU BXM 4-64 MC1; Video Engine; Security System; DDR; AXP318; NAND; eMMC; GPADCx7; LVDS; MIPI-CSI; POWER; RTC; DCXO; SDIO; USB0(OTG); USB1(HOST); TWIx13; UARTx7; SPIx4; LRADCx1; DMICx8; S-UART x2; S-PWM x10; I2S&PCMx4; S-TWI 1/2; TYPE-C Port; RGB; MIPI-DSI; VBUS; 32.768KHz; 26MHz; MEMORY; AUDIO; CPUS AR100; NNECTO; WIFI&BT; LPDDR4; SPDIFOUT; S-TWI0; PWMx20; SYSTEM; USB&PCIE; HDMI; PCIe3.0&USB3.1 combo*2; USB2; USBC0; USB0; S_TWI0; S-SPI0; USB1; UFS; UFS3.1; BLOCK; USBC2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

ADC DISPLAY CAMERA

0.8-1V

0.8V-0.96V

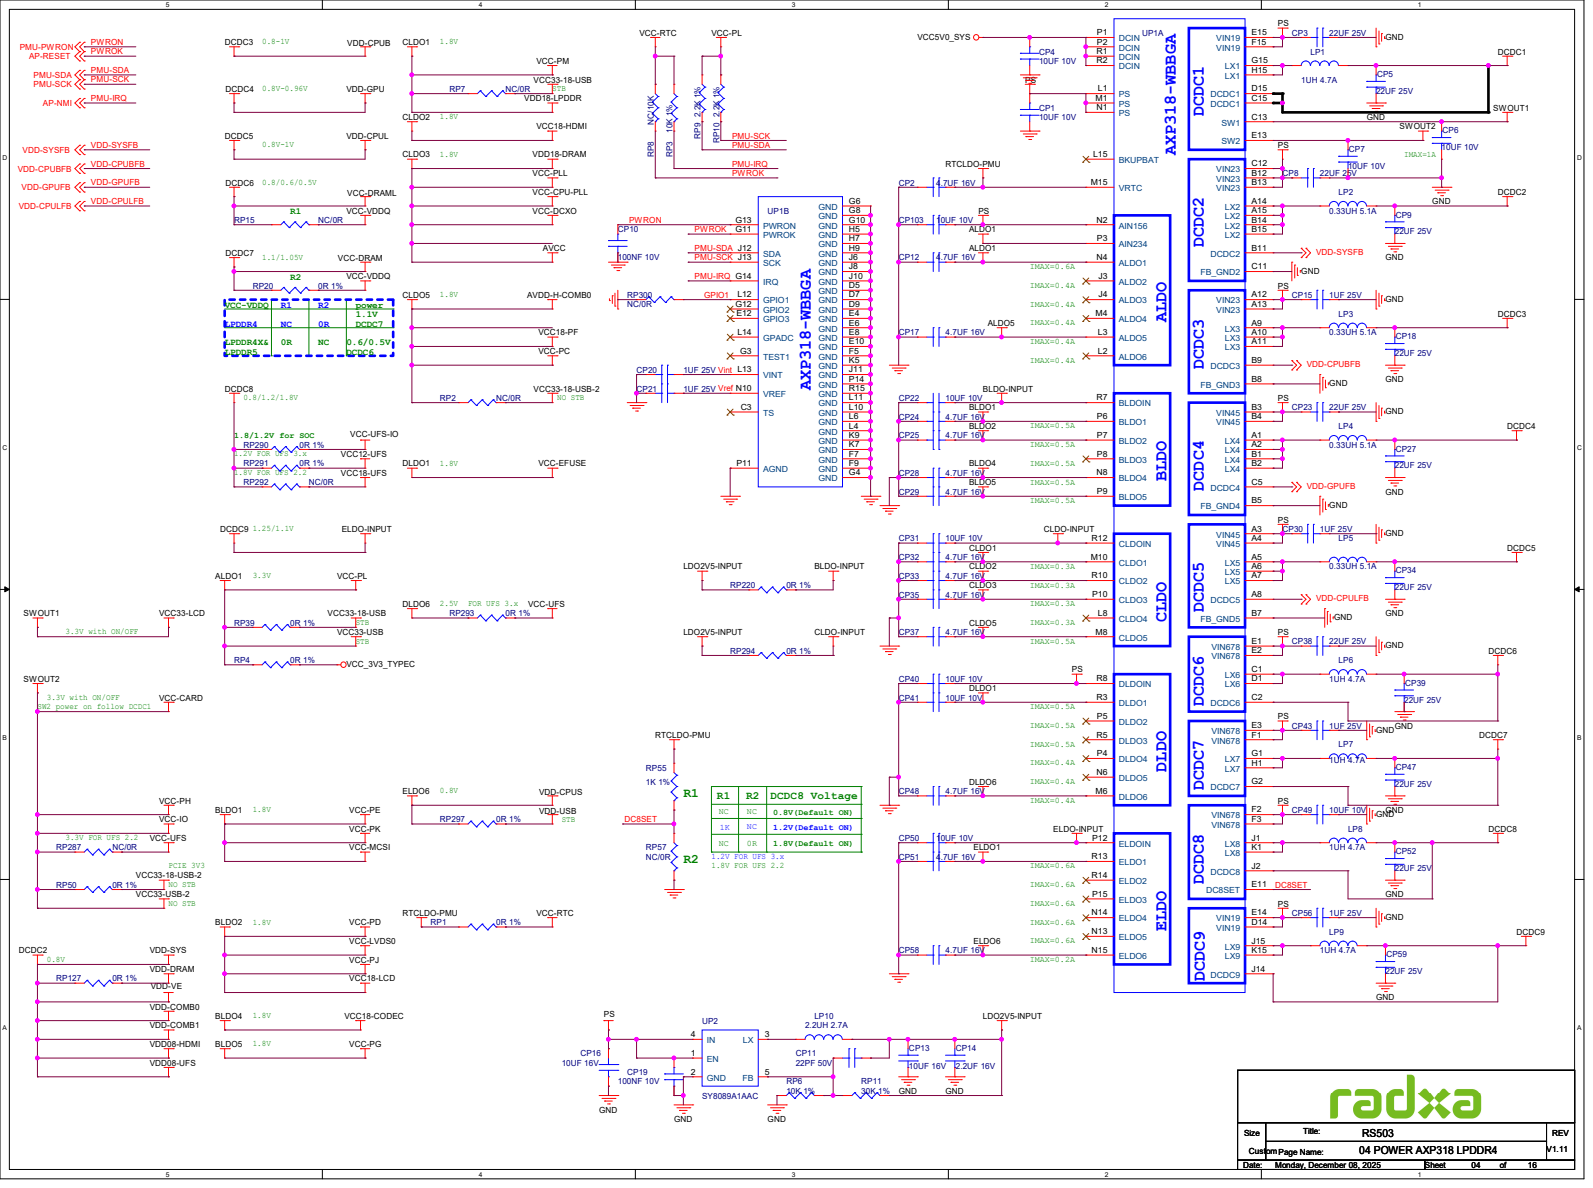
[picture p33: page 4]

R1 | R2 | DCDC8 Voltage
NC | NC | 0.8V(Default ON)
1K | NC | 1.2V(Default ON)

# LPDDR4

## VCC-DRAM

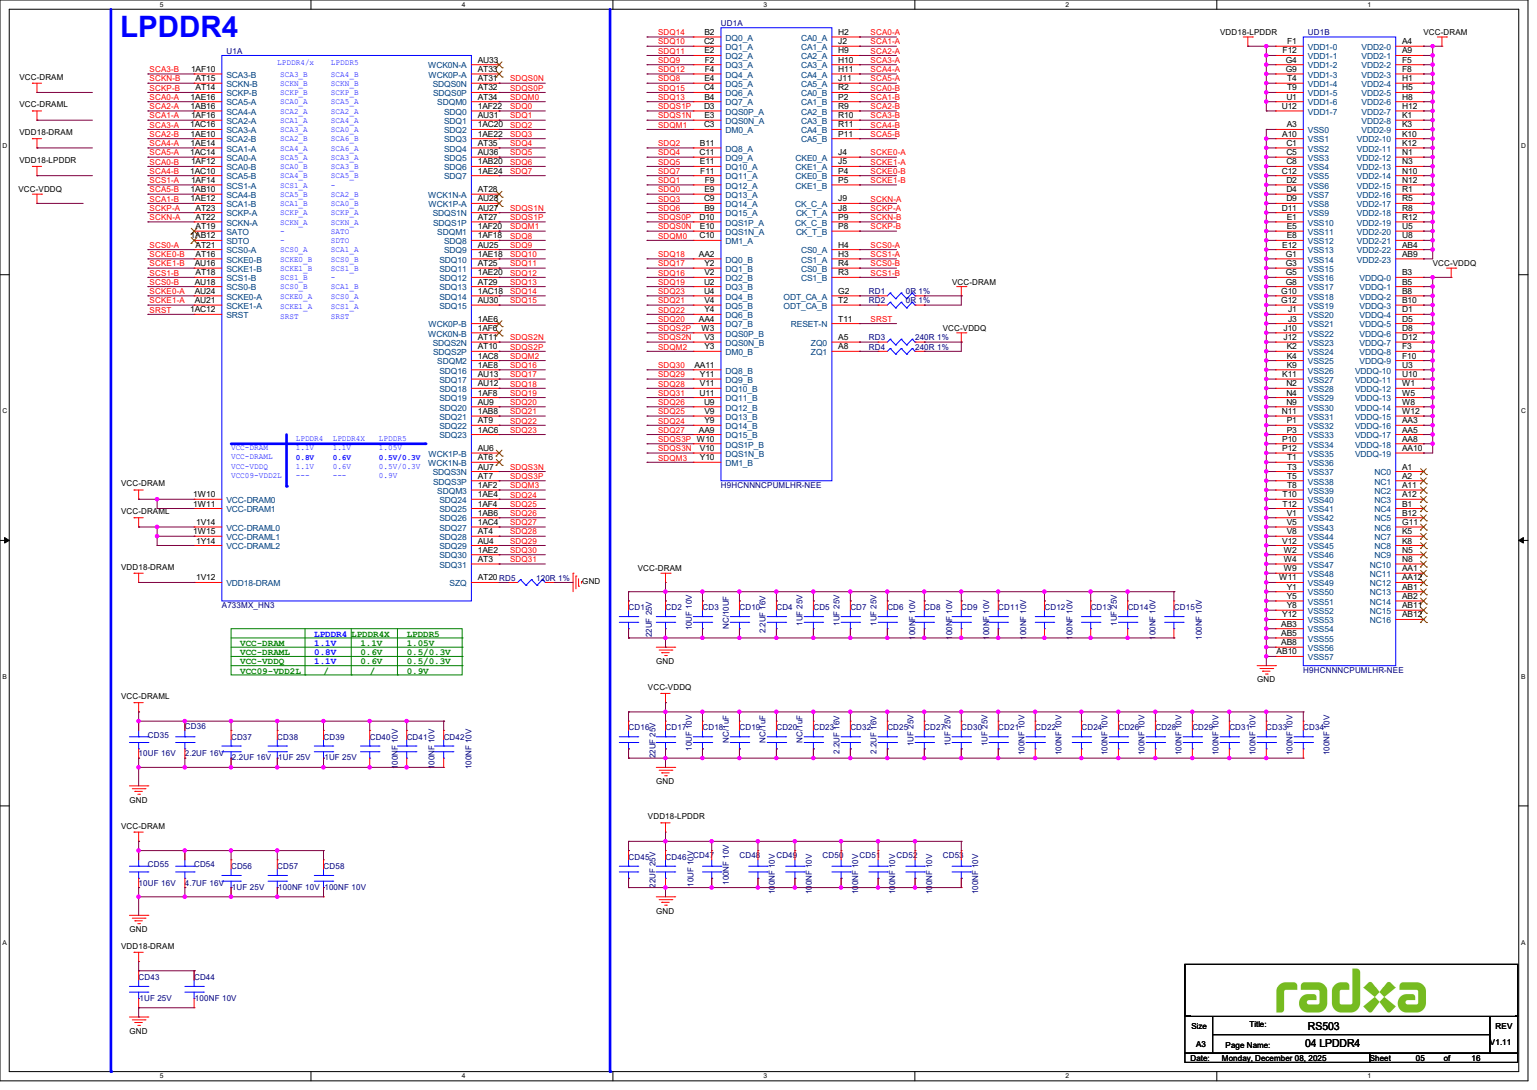
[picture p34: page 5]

# ADC

# DDR PARA

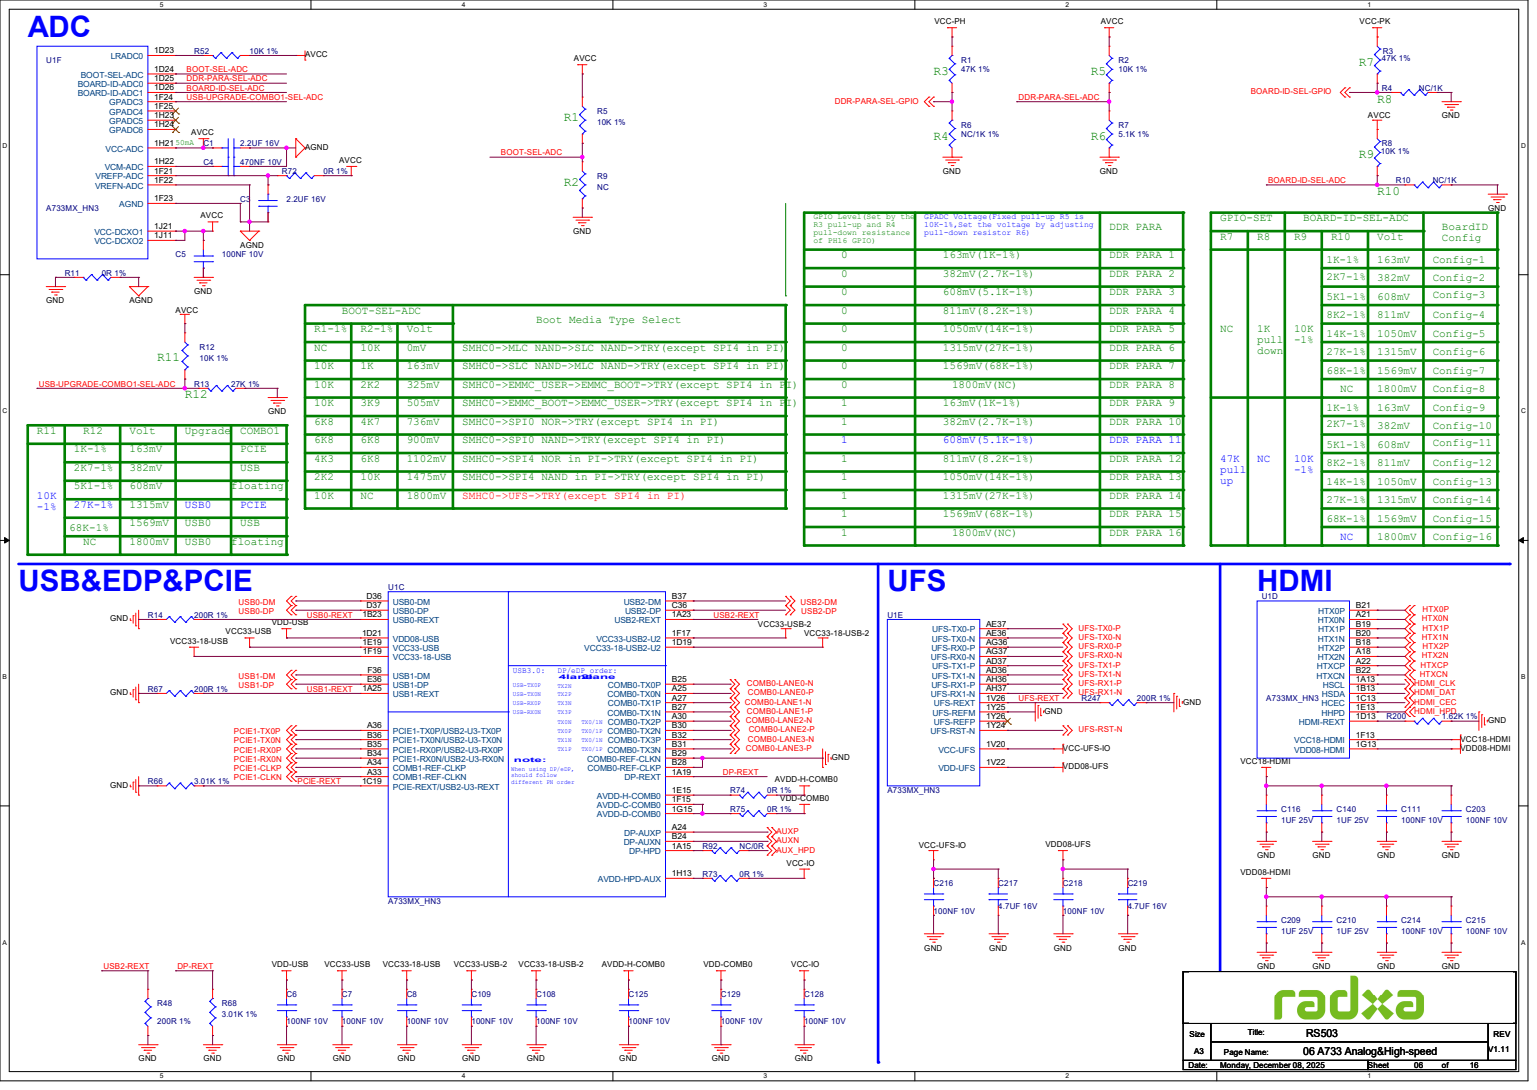
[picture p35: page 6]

DDR-PARA-SEL-GPIO

DDR-PARA-SEL-ADC

BOARD-ID-SEL-GPIO

BOARD-ID-SEL-ADC

Boot Media Type Select

SMHC0->MLC NAND->SLC NAND->TRY(except SPI4 in PI)
SMHC0->SLC NAND->MLC NAND->TRY(except SPI4 in PI)
SMHC0->EMMC_USER->EMMC_BOOT->TRY(except SPI4 in PI)
SMHC0->EMMC_BOOT->EMMC_USER->TRY(except SPI4 in PI)

USB-UPGRADE-COMBO1-SEL-ADC

R11 | R12 | Volt | Upgrade | COMBO1
10K -1% | 1K-1% | 163mV | | PCIE
2K7-1% | 382mV | | USB
5K1-1% | 608mV | | floating
27K-1% | 1315mV | USB0 | PCIE
68K-1% | 1569mV | USB0 | USB
NC | 1800mV | USB0 | floating

SMHC0->SPI0 NAND->TRY(except SPI4 in PI)
SMHC0->SPI4 NOR in PI->TRY(except SPI4 in PI)
SMHC0->SPI4 NAND in PI->TRY(except SPI4 in PI)
SMHC0->UFS->TRY(except SPI4 in PI)

note:
When using DP/eDP,
should follow
different PN order

# GPIO

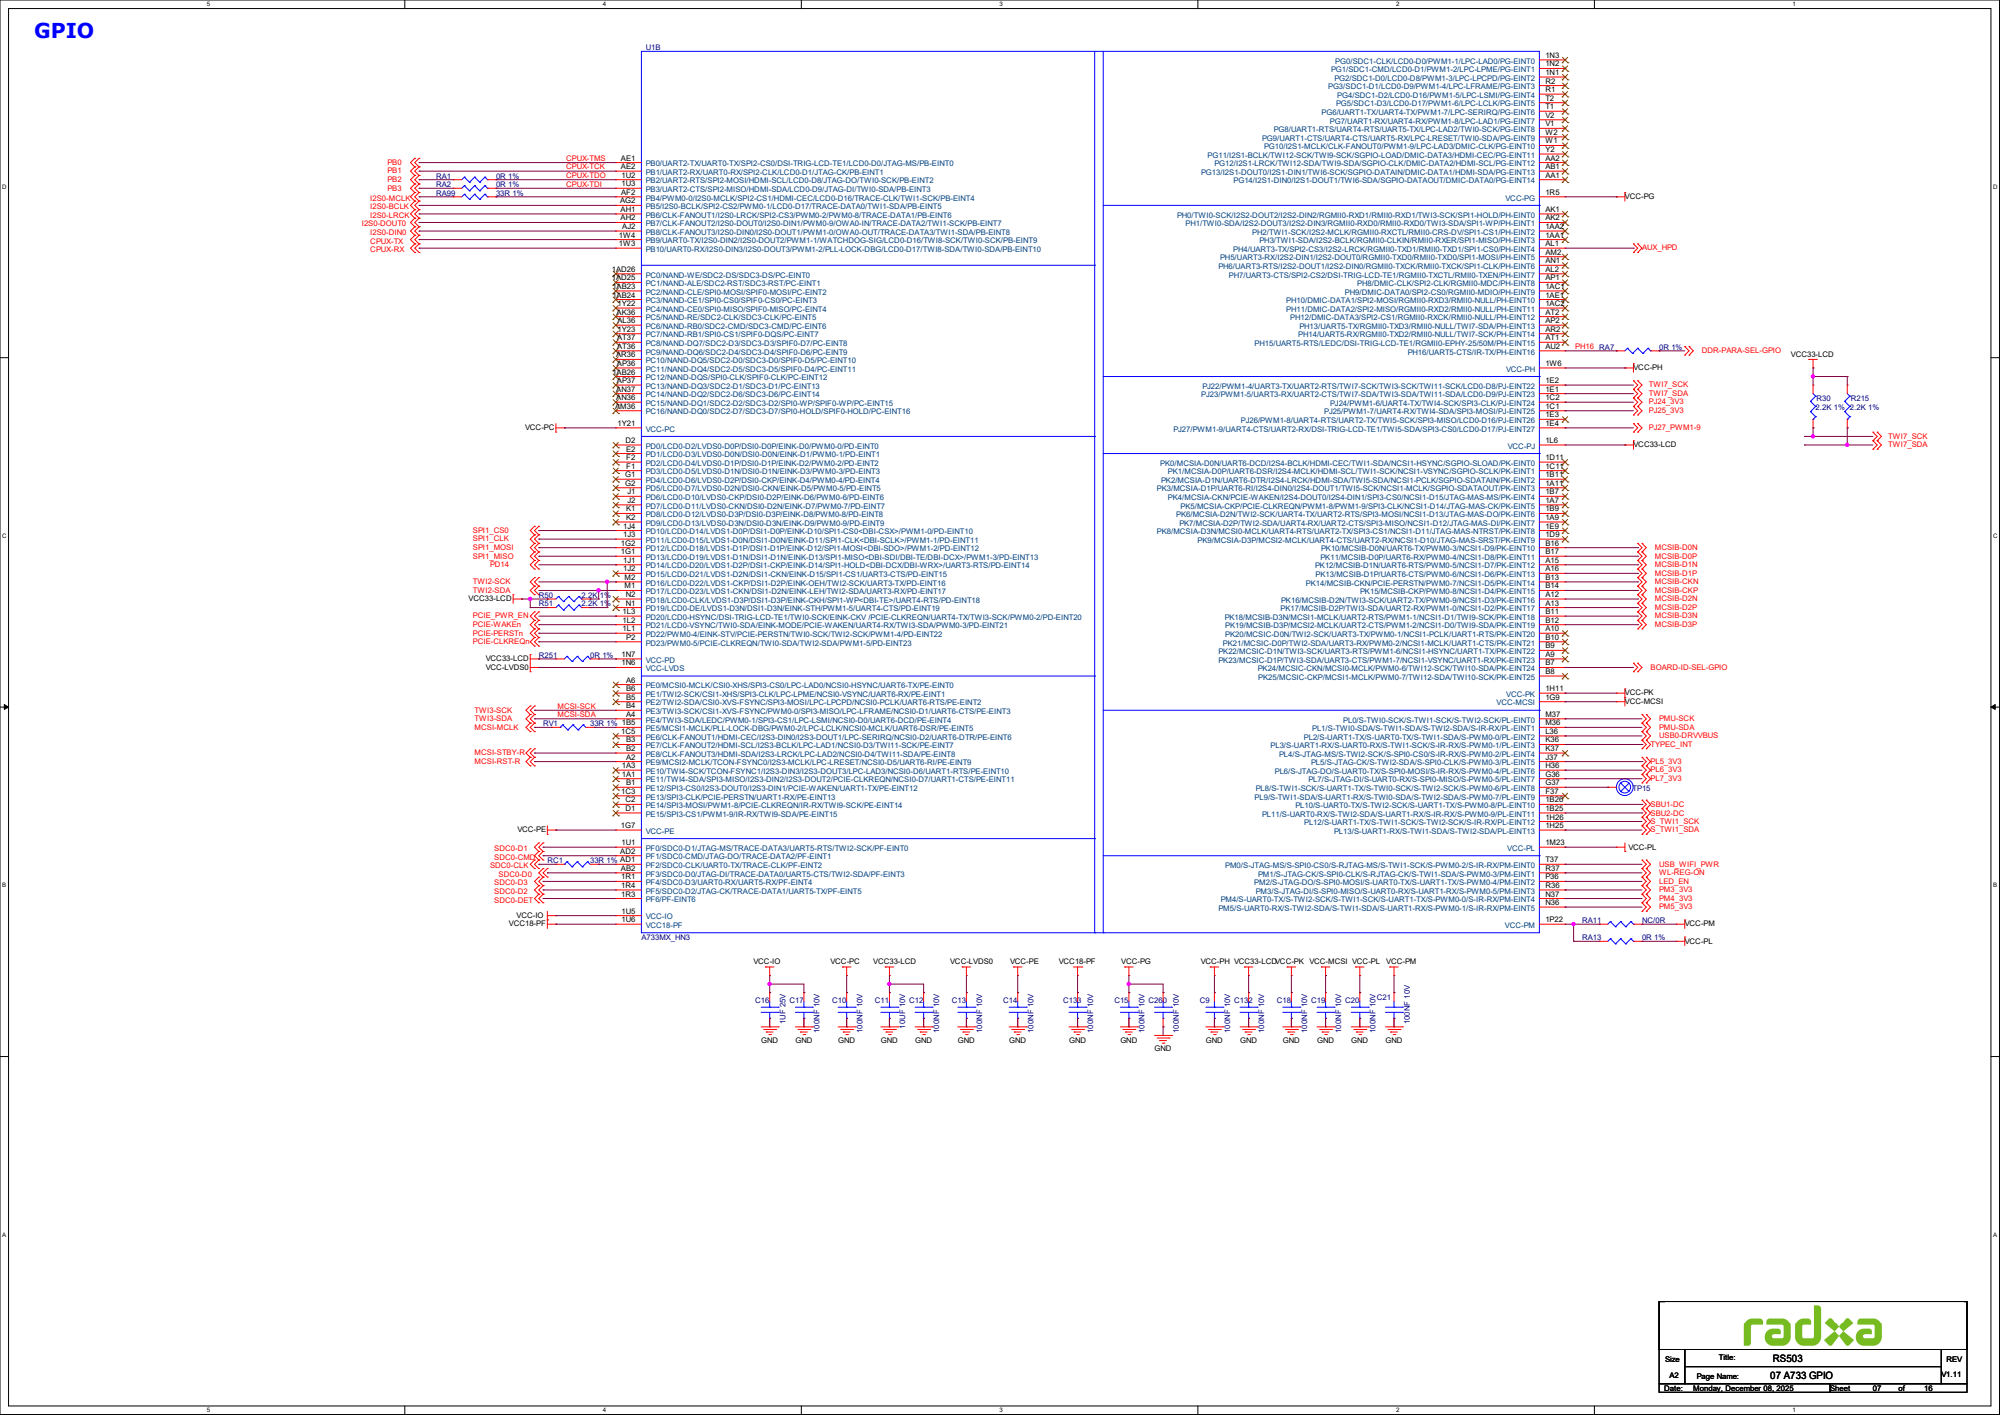
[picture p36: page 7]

PG0/SDC1-CLK/LCD0-D0/PWM1-1/LPC-LAD0/PG-EINT0
PG1/SDC1-CMD/LCD0-D1/PWM1-2/LPC-LPME/PG-EINT1
PG2/SDC1-D0/LCD0-D8/PWM1-3/LPC-LPCPD/PG-EINT2
PG3/SDC1-D1/LCD0-D9/PWM1-4/LPC-LFRAME/PG-EINT3
PG4/SDC1-D2/LCD0-D16/PWM1-5/LPC-LSMI/PG-EINT4
PG5/SDC1-D3/LCD0-D17/PWM1-6/LPC-LCLK/PG-EINT5
PG6/UART1-TX/UART4-TX/PWM1-7/LPC-SERIRQ/PG-EINT6
PG7/UART1-RX/UART4-RX/PWM1-8/LPC-LAD1/PG-EINT7

PG8/UART1-RTS/UART4-RTS/UART5-TX/LPC-LAD2/TWI0-SCK/PG-EINT8
PG9/UART1-CTS/UART4-CTS/UART5-RX/LPC-LRESET/TWI0-SDA/PG-EINT9
PG10/I2S1-MCLK/CLK-FANOUT0/PWM1-9/LPC-LAD3/DMIC-CLK/PG-EINT10

PB0/UART2-TX/UART0-TX/SPI2-CS0/DSI-TRIG-LCD-TE1/LCD0-D0/JTAG-MS/PB-EINT0
PB1/UART2-RX/UART0-RX/SPI2-CLK/LCD0-D1/JTAG-CK/PB-EINT1
PB2/UART2-RTS/SPI2-MOSI/HDMI-SCL/LCD0-D8/JTAG-DO/TWI0-SCK/PB-EINT2
PB3/UART2-CTS/SPI2-MISO/HDMI-SDA/LCD0-D9/JTAG-DI/TWI0-SDA/PB-EINT3
PB4/PWM0-0/I2S0-MCLK/SPI2-CS1/HDMI-CEC/LCD0-D16/TRACE-CLK/TWI1-SCK/PB-EINT4
PB5/I2S0-BCLK/SPI2-CS2/PWM0-1/LCD0-D17/TRACE-DATA0/TWI1-SDA/PB-EINT5
PB6/CLK-FANOUT1/I2S0-LRCK/SPI2-CS3/PWM0-2/PWM0-8/TRACE-DATA1/PB-EINT6
PB7/CLK-FANOUT2/I2S0-DOUT0/I2S0-DIN1/PWM0-9/OWA0-IN/TRACE-DATA2/TWI1-SCK/PB-EINT7
PB8/CLK-FANOUT3/I2S0-DIN0/I2S0-DOUT1/PWM1-0/OWA0-OUT/TRACE-DATA3/TWI1-SDA/PB-EINT8
PB9/UART0-TX/I2S0-DIN2/I2S0-DOUT2/PWM1-1/WATCHDOG-SIG/LCD0-D16/TWI8-SCK/TWI0-SCK/PB-EINT9
PB10/UART0-RX/I2S0-DIN3/I2S0-DOUT3/PWM1-2/PLL-LOCK-DBG/LCD0-D17/TWI8-SDA/TWI0-SDA/PB-EINT10

PG11/I2S1-BCLK/TWI12-SCK/TWI9-SCK/SGPIO-LOAD/DMIC-DATA3/HDMI-CEC/PG-EINT11
PG12/I2S1-LRCK/TWI12-SDA/TWI9-SDA/SGPIO-CLK/DMIC-DATA2/HDMI-SCL/PG-EINT12
PG13/I2S1-DOUT0/I2S1-DIN1/TWI6-SCK/SGPIO-DATAIN/DMIC-DATA1/HDMI-SDA/PG-EINT13

PG14/I2S1-DIN0/I2S1-DOUT1/TWI6-SDA/SGPIO-DATAOUT/DMIC-DATA0/PG-EINT14

PH0/TWI0-SCK/I2S2-DOUT2/I2S2-DIN2/RGMII0-RXD1/RMII0-RXD1/TWI3-SCK/SPI1-HOLD/PH-EINT0
PH1/TWI0-SDA/I2S2-DOUT3/I2S2-DIN3/RGMII0-RXD0/RMII0-RXD0/TWI3-SDA/SPI1-WP/PH-EINT1

PH2/TWI1-SCK/I2S2-MCLK/RGMII0-RXCTL/RMII0-CRS-DV/SPI1-CS1/PH-EINT2
PH3/TWI1-SDA/I2S2-BCLK/RGMII0-CLKIN/RMII0-RXER/SPI1-MISO/PH-EINT3
PH4/UART3-TX/SPI2-CS3/I2S2-LRCK/RGMII0-TXD1/RMII0-TXD1/SPI1-CS0/PH-EINT4
PH5/UART3-RX/I2S2-DIN1/I2S2-DOUT0/RGMII0-TXD0/RMII0-TXD0/SPI1-MOSI/PH-EINT5
PH6/UART3-RTS/I2S2-DOUT1/I2S2-DIN0/RGMII0-TXCK/RMII0-TXCK/SPI1-CLK/PH-EINT6
PH7/UART3-CTS/SPI2-CS2/DSI-TRIG-LCD-TE1/RGMII0-TXCTL/RMII0-TXEN/PH-EINT7
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

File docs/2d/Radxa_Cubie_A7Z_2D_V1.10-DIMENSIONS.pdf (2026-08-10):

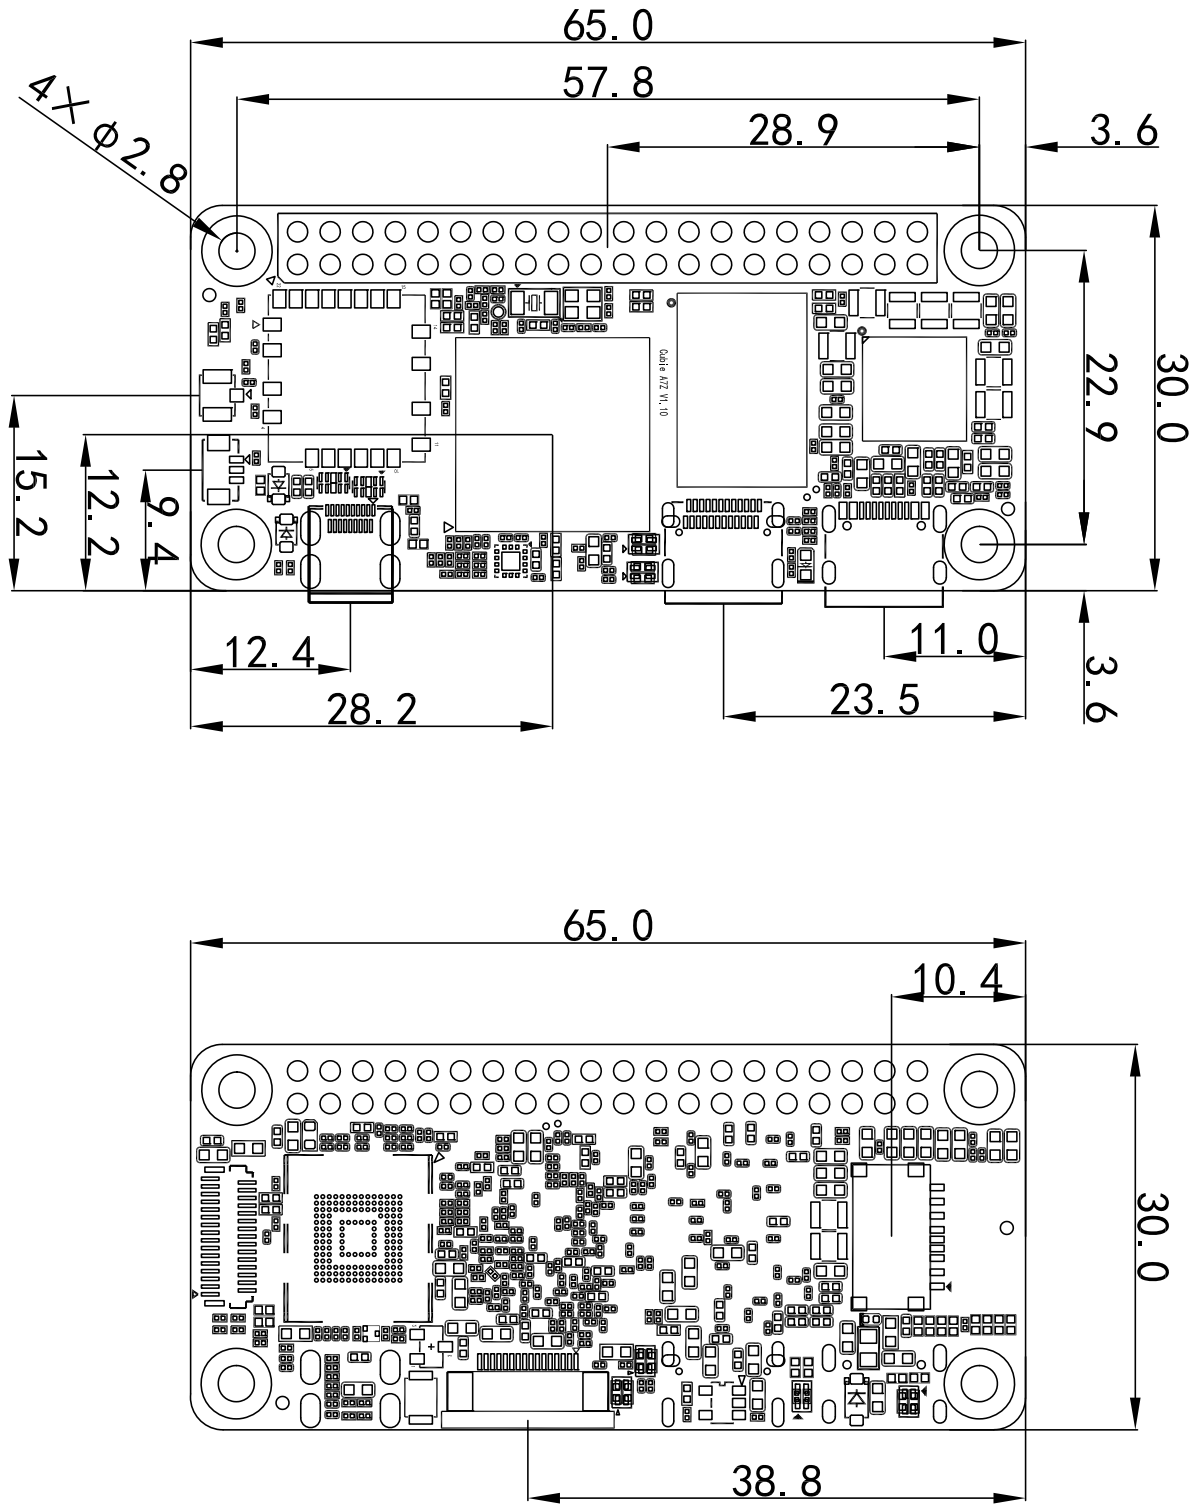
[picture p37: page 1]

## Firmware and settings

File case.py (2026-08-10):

"""Radxa Cubie A7Z enclosure, generated with CadQuery.

Two pieces: a bottom tray the board drops into and a friction-fit snap lid.
Dimensions come from Radxa's official mechanical data in ./docs/ — the 2D
dimension drawing (65.0 x 30.0 mm outline, 4x2.8 mm holes on a 57.8 x 22.9
grid, 3.6 mm from the edges) and the 3D STEP of the board, which was probed
solid-by-solid for the connector positions below.

Coordinates: x across the board width (0 at the GPIO edge, 30.01 at the
ports edge), y along the length (0 at the fan/antenna end), z = 0 at the
PCB bottom face.

Run:  uv run case.py
Outputs STEP + STLs into ./output/.
"""

import os

import cadquery as cq

# --- board facts (probed from docs/3d/Radxa_Cubie_A7Z_3D_STP_V1.10.stp) ---
PCB_W = 30.01
PCB_L = 65.02
PCB_T = 1.2
HOLE_D = 2.8
HOLES = [(3.56, 3.61), (26.46, 3.61), (3.56, 61.41), (26.46, 61.41)]

GPIO = (0.79, 5.87, 7.07, 57.87)     # x0, x1, y0, y1; pins top out 8.3 above PCB
GPIO_H = 8.3

# ports edge (x = 30.01); all three shells overhang the board edge by 1.0
HDMI_Y = (9.27, 15.77)               # micro HDMI shell, z 0.66..4.10
USB3_Y = (37.01, 45.95)              # USB-C 3.1 / DP alt mode, z 1.24..4.40
PWR_Y = (49.56, 58.50)               # USB-C 2.0 / power + OTG, z 1.24..4.40

# bottom side. Three parts hang under the board, and the STEP models only
# two of them — as truncated blocks, with no names. An earlier revision read
# the wrong one as the card slot, so both are pinned down here:
#   MIPI CSI FPC, at the y=0 short edge — 10.80 wide x 3.25 deep x 1.00 tall
#   is a 0.5 mm-pitch FPC connector, not a card holder. Its ribbon leaves
#   under the board over that edge.
#   PCIe Gen3 FPC, at the ports long edge mid-board — 13.70 long x 4.26 deep,
#   likewise an FPC connector; its ribbon leaves under the board sideways.
# The microSD is absent from the STEP entirely, which is what let the CSI
# connector pass for it: 10.80 wide reads a lot like an 11.0 mm card. It is
# at the *other* short edge (y=65), also on the bottom, and two independent
# sources agree on where. Radxa's interface photo
# (docs.radxa.com/img/cubie/a7z/a7z-interface.webp) puts the holder shell at
# x 9.7..20.6, y 52.1..57.4 when scaled against the known 30.01 x 65.02
# outline; the bottom DXF has the holder's contact row there too — nine pads
# in microSD's 1.10/0.70 mm pitch pattern, x 11.14..18.84, y 57.85..58.93.
# The same photo shows the CSI FPC connector at the y=0 edge, x 9.8..19.1,
# on the bottom face, which is the block the STEP does model.
CSI_X = (9.61, 20.41)                # MIPI CSI FPC, y 1.32..4.57, z -1.00..0
PCIE = (25.05, 29.31, 19.42, 33.12)  # x0, x1, y0, y1; z -1.20..0
SD_X = (9.65, 20.65)                 # microSD holder shell, y 52.1..59.4
SD_DROP = 1.4                        # holder hang below the PCB. Not in the
                                     # STEP; a generic push-pull holder.
# A 15.0 mm card bottoms out with its leading edge at the back of the shell
# (y ~52.2), so its other end lands at y ~67.2 — level with the outer wall
# face at 67.12. Flush is not grippable, hence the scallop around the slot.
# USB BOOT button: bottom side, just behind the micro HDMI port. A 3.00 x
# 2.50 x 1.00 tact switch at x 26.01..29.01, y 16.69..19.19. Confirmed two
# ways, because the board has a second, similar-looking part at y 51.9 that
# an earlier revision used by mistake: the placement map's SW1 designator
# lands at (26.95, 17.95) once the bottom view's mirrored x is undone, and
# the switch is where the hardware says it is.
SW1 = (27.51, 17.94)
BOTTOM_DROP = SD_DROP                # deepest bottom-side part

# The y = 65 edge carries nothing on the top side — everything at that end
# (the microSD holder) is underneath.
# y = 0 edge, top side: fan header (x 18.25..23.00, 3.1 tall) and the
# antenna U.FL (x 13.31..16.31, 2.5 tall); both need a cable path out
ANT_FAN_X = (12.8, 23.5)

# Status LED, in the 2.2 mm gap between the two USB-C ports. The window has
# to thread a needle: at Ø2.0 it overran the lip's inner face (x = 28.96) on
# one side and the power port's notch (y = 48.86) on the other, by about
# 0.05 each, nicking both. Ø1.6 clears everything and still sits over the
# emitter, which spans y 47.27..48.54.
LED = (28.01, 47.91)
LED_D = 1.6
SOC = (10.30, 25.40, 20.65, 35.75)   # Allwinner A733, vent slots go above it

# --- case parameters ---
CLR = 0.3        # board clearance per side
WALL = 1.8
FLOOR = 1.4      # 7 layers at 0.2; plenty over a footprint this small
STANDOFF = 1.6   # board bottom above the tray floor; bottom parts reach 1.27
SHELL_TOP = 4.40  # tallest port shell, measured from the PCB bottom face
FAN_HDR_TOP = 3.10  # tallest part that isn't a port shell

# Cavity height above the PCB top, and the one number that sets how tall the
# case is. Two settings:
#
#   standard — clears the USB-C shells, so the lid closes over the port
#     notches and the ports read as slots in the tray wall alone. Also
#     leaves 1.6 mm above the fan header for a fan cable.
#   slim — clears the fan header and nothing more. The shells now stand
#     proud of the cavity, so the port notches carry on through the lid and
#     open at the top edge; the case loses 1.3 mm. No room for a fan lead,
#     which is the trade.
#
# Below the standard figure the lid would foul the shells; above it, every
# extra millimetre shows up as slop above the ports.
HEADROOM_STD = SHELL_TOP + 0.3 - PCB_T
HEADROOM_SLIM = FAN_HDR_TOP + 0.3 - PCB_T
LID_T = 1.4      # 0.6 of that is engraving depth, leaving 0.8 of skin

CAV_X0, CAV_X1 = -CLR, PCB_W + CLR
CAV_Y0, CAV_Y1 = -CLR, PCB_L + CLR
OUT_X0, OUT_X1 = CAV_X0 - WALL, CAV_X1 + WALL
OUT_Y0, OUT_Y1 = CAV_Y0 - WALL, CAV_Y1 + WALL
Z_FLOOR = -STANDOFF - FLOOR          # outer bottom face
CORNER_R = 4.0
EDGE_CHAMFER = 0.8  # bed-facing outer edges. A fillet there would curve out
                    # to a 90° overhang on the first layers; 45° prints clean.

LIP_T = 1.2
LIP_H = 1.6
LIP_CLR = 0.15   # per side

# Set per variant by use_headroom(); the geometry below reads them as
# globals so both heights share one set of builders.
CAV_TOP = SNAP_Z = None
notches = lip_clears = recesses = sd_slot = aux_notches = None
shell_notches = None
PORTS_THROUGH_LID = False
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

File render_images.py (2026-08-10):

"""Regenerate the README images in images/.

Runs case.py in full (checks and all), projects the parts as line art, and
writes tightly-cropped PNGs. Rasterising uses macOS qlmanage; on another
platform swap in any SVG-to-PNG converter.

Run:  uv run render_images.py
"""

import os
import runpy
import subprocess

from PIL import Image, ImageChops

here = os.path.dirname(os.path.abspath(__file__))
imgdir = os.path.join(here, "images")
os.makedirs(imgdir, exist_ok=True)

g = runpy.run_path(os.path.join(here, "case.py"))
cq = g["cq"]

# The SVG exporter builds its 2D basis so that most isometric directions
# come out mirrored — engraved text reads backwards. This one doesn't.
ISO = (-1, -1, 0.85)
PAD = 18          # px of white left around the geometry
TARGET_W = 1200   # px, downsampled for a clean line weight
TARGET_H = 900


def group(*parts):
    """One compound so a scene projects as a single drawing."""
    return cq.Compound.makeCompound(
        [p if isinstance(p, cq.Shape) else p.val() for p in parts])


bottom, bottom_s = g["bottom"], g["bottom_s"]
lid, lid_c, lid_cp = g["lid"], g["lid_c"], g["lid_cp"]
bottom_lo, lid_lo, lid_lo_cp = g["bottom_lo"], g["lid_lo"], g["lid_lo_cp"]

# Parts are drawn one per image rather than lined up in a shared scene: the
# projection turns an x-offset into a diagonal one, so laid-out parts drift
# apart and waste half the frame. Separate images crop tight and sit in a
# table in the README.
# (shape, projection, degrees to turn the finished image, counter-clockwise).
# The exporter picks its own up-vector per projection direction and lands
# straight-on elevations on their side — and not consistently the same
# side, hence the opposite turns for the two below. Check a new elevation
# against a known landmark (the tray/lid seam sits 1.6 mm below the top)
# rather than assuming.
scenes = {
    "case-open": (group(bottom, lid), ISO, 0),
    "case-closed": (group(bottom, lid_c), ISO, 0),
    "board-in-tray": (group(bottom, g["mock"]), ISO, 0),
    "tray-full": (bottom, ISO, 0),
    "tray-sealed": (bottom_s, ISO, 0),
    "tray-slim": (bottom_lo, ISO, 0),
    "lid-open": (lid, ISO, 0),
    "lid-closed": (lid_c, ISO, 0),
    "lid-plain": (lid_cp, ISO, 0),
    "lid-slim": (lid_lo, ISO, 0),
    "lid-slim-closed": (lid_lo_cp, ISO, 0),
    "lid-slim-plain": (g["lid_lo_p"], ISO, 0),
    "case-slim": (group(bottom_lo, lid_lo), ISO, 0),
    "ports-slim": (group(bottom_lo, lid_lo), (1, 0.001, 0.001), 90),
    "lid-top": (lid, (0, 0, 1), 0),
    "ports": (group(bottom, lid), (1, 0.001, 0.001), 90),
    "sd-end": (group(bottom, lid), (0.001, 1, 0.001), 90),
    "cable-end": (group(bottom, lid), (0.001, -1, 0.001), -90),
    "underside": (bottom, (0.001, 0.001, -1), 0),
}

def render(shape, dirn, svg, canvas_w, canvas_h):
    cq.exporters.export(shape, svg, opt={
        "projectionDir": dirn, "width": canvas_w, "height": canvas_h,
        "marginLeft": 60, "marginTop": 60,
        "showAxes": False, "showHidden": False, "strokeWidth": 0.3,
    })
    subprocess.run(["qlmanage", "-t", "-s", str(max(canvas_w, canvas_h)),
                    "-o", imgdir, svg], check=True, capture_output=True)
    im = Image.open(svg + ".png").convert("RGB")
    bbox = ImageChops.difference(
        im, Image.new("RGB", im.size, (255, 255, 255))).getbbox()
    os.remove(svg + ".png")
    os.remove(svg)
    return im, bbox


for name, (shape, dirn, turn) in scenes.items():
    svg = os.path.join(imgdir, name + ".svg")
    # The exporter scales the drawing to fit the canvas *height* and lets a
    # wide part run off the sides, so widen and retry until the ink stops
    # touching the frame.
    canvas_w, canvas_h = 3000, 2400
    for _ in range(5):
        im, bbox = render(shape, dirn, svg, canvas_w, canvas_h)
        l, t, r, b = bbox
        if l > 1 and t > 1 and r < im.width - 1 and b < im.height - 1:
            break
        canvas_w = round(canvas_w * 1.6)

    im = im.crop((max(l - PAD, 0), max(t - PAD, 0),
                  min(r + PAD, im.width), min(b + PAD, im.height)))
    if turn:
        im = im.rotate(turn, expand=True, fillcolor=(255, 255, 255))
    scale = min(TARGET_W / im.width, TARGET_H / im.height, 1.0)
    if scale < 1.0:
        im = im.resize((round(im.width * scale), round(im.height * scale)),
                       Image.LANCZOS)
    im.save(os.path.join(imgdir, name + ".png"), optimize=True)
    print(f"{name}  {im.width}x{im.height}")
